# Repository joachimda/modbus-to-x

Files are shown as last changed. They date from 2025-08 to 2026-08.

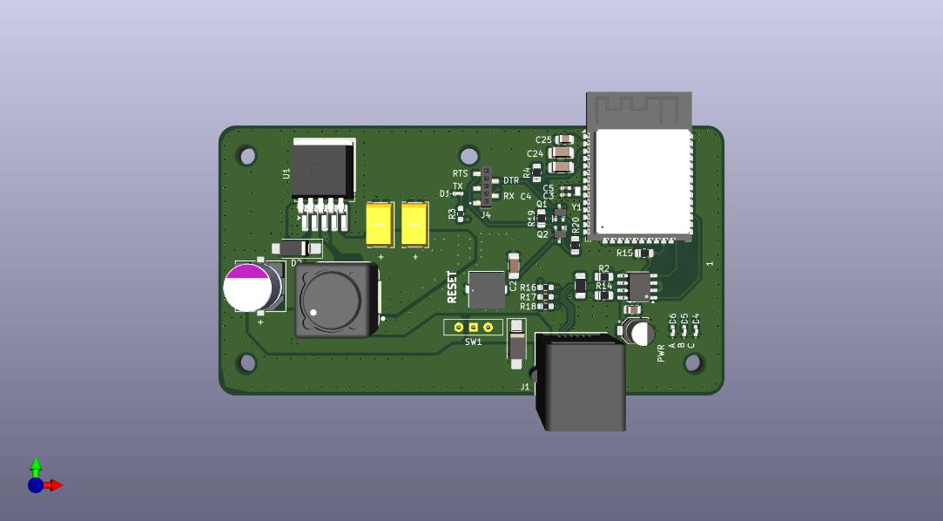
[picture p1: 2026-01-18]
hardware/mbx_3d_view.jpg

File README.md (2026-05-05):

# Modbus-to-X

An ESP32-based hardware and firmware stack that bridges RS-485/Modbus field devices to modern network services such as MQTT, with a configuration-first UX for installers and maintainers.

## Table of Contents
- [Overview](#overview)
- [Architecture](#architecture)
  - [Hardware](#hardware)
  - [Firmware](#firmware)
- [Getting Started](#getting-started)
  - [Prerequisites](#prerequisites)
  - [Build and Flash](#build-and-flash)
  - [Release Automation](#release-automation)
  - [Local UI Development](#local-ui-development)
- [Usage](#usage)
  - [First Boot and Network Setup](#first-boot-and-network-setup)
  - [Configuring Modbus Devices](#configuring-modbus-devices)
  - [MQTT Publishing](#mqtt-publishing)
- [Project Structure](#project-structure)
  - [Hardware Documentation](#hardware-documentation)
  - [Software Documentation](#software-documentation)
- [Acknowledgements](#acknowledgements)

## Overview
Modbus-to-X combines a custom ESP32 carrier board with firmware that polls Modbus RTU devices over RS-485, persists telemetry locally, and republishes structured payloads to MQTT brokers. 
The firmware exposes an onboard web interface for Wi-Fi provisioning, Modbus configuration, live device statistics, and log retrieval so field technicians can deploy the gateway without recompiling binaries.

## Architecture
The project is split between dedicated hardware design files and a PlatformIO firmware project. Hardware-specific documentation lives in [`hardware/`](hardware/); firmware, tooling, and UI assets live in [`software/`](software/).

### Hardware
- Four-layer ESP32 carrier featuring an ESP32-WROOM-32D module, MAX3485 RS-485 transceiver
- RJ12 Connector exposing differential RS-485 pair alongside field power for quick deployment.
- Wide input voltage range (4.5 - 40V)
- Supporting assets include datasheets, fabrication rules, and release notes for each board revision under `hardware/`.

### Firmware
- PlatformIO-based ESP32 application primarily built with the Arduino framework.
- Library dependencies: ModbusMaster, PubSubClient, ArduinoJson, and ESPAsyncWebServer for protocol handling and a dynamic UI backend.
- A custom partition table separates user configurations from UI components, leaving user configurations untouched on filesystem uploads.
- Boot sequence mounts filesystem partitions, starts the async web server ("MBX Server"), initializes the Modbus scheduler, and spins up the MQTT manager.
- Configuration data for the Modbus bus, devices, and MQTT settings is stored in `/conf/*.json` on the dedicated config SPIFFS partition (`cfg`) and hot-reloaded without reflashing.
- MQTT passwords are stored in NVS preferences; `/conf/mqtt.json` contains non-sensitive fields.
- Default wiring, RS-485 guard times, Wi-Fi AP Portal credentials, and OTA parameters are centralized in [`Config.h`](software/modbus-to-mqtt/include/Config.h).

## Getting Started

### Prerequisites
- Modbus-to-X hardware (v0.2 alpha or later) and Modbus RTU devices wired to the RS-485 terminals.
- 4.5–40 VDC field power (buck input validated in the current design) and a USB-to-UART adapter if not using OTA uploads.
- Development host with Python 3, [PlatformIO Core](https://platformio.org/install/cli), and a working `git` toolchain. Required Python build dependencies are installed automatically by `scripts/install_build_deps.py` when PlatformIO runs.

### Build and Flash
1. Clone the repository and enter the firmware workspace:
   ```bash
   git clone https://github.com/joachimda/modbus-to-x.git
   cd modbus-to-x/software/modbus-to-mqtt
   ```
2. Choose an environment in `platformio.ini`:
   - `mbx-custom-board-dev` — development build, serial upload (default).
   - `mbx-custom-board-dev-ota` — development build, OTA upload (configure `upload_port` for your device).
   - `mbx-custom-board-release` — release build (used by the GitHub Actions workflow).
   - `mbx-custom-board-release-primer` — primes a dev device to receive HTTP OTA updates.
3. Build the firmware (PlatformIO will fetch dependencies and embed git metadata):
   ```bash
   pio run
   ```
4. Flash via USB/UART or OTA by selecting the matching environment:
   ```bash
   # Serial upload
   pio run -e mbx-custom-board-dev -t upload

   # OTA upload to a provisioned gateway
   pio run -e mbx-custom-board-dev-ota -t upload
   ```
5. Upload the web UI and config assets to SPIFFS when they change:
   ```bash
   pio run -e mbx-custom-board-dev -t uploadfs
   ```

### Release Automation
Pushing a `v*` tag triggers the GitHub Actions workflow in `.github/workflows/main.yml` to build firmware + filesystem images and create a GitHub Release with the assets:
- `modbus-to-x.bin` (firmware)
- `modbus-to-x.fs.bin` (filesystem)
- `modbus-to-x.notes.txt` (release notes generated from the commit log since the previous tag)
- `modbus-to-x.manifest.json` (includes SHA-256 hashes and a signature generated from `OTA_SIGNING_KEY_PEM` and `KID`).

### Local UI Development
The `scripts/run_test_webserver.py` helper serves the `data/` directory with mocked API responses so you can iterate on the HTML/JS bundle without flashing the device:
```bash
cd software/modbus-to-mqtt
python scripts/run_test_webserver.py
# Visit http://127.0.0.1:8000
```
It injects correct MIME types, disables caching, and emulates `/api/stats/system`, `/api/events`, `/api/logs`, and `/api/system/reboot` for the SPA.

## Usage

### First Boot and Network Setup
1. Power the gateway; it will advertise a Wi-Fi AP using the defaults defined in `Config.h` (`MODBUS-MQTT-BRIDGE` / `you-shall-not-pass`).
2. Connect to the AP. The ESP will try getting 192.168.4.1 from DHCP. If supported on your OS, you will be prompted to open the Captive Portal and redirected automatically. If these fail, check your router for the device's IP address, and use your browser to open the configuration page `http://192.168.4.1/`. 
3. Follow the on-screen guidance to scan, join, or provision hidden networks, optionally specifying static IP parameters before saving.
4. After a successful network connection is established, reboot the device.

### Configuring Modbus Devices
- Use **Configure Modbus** to edit the RS-485 bus, add devices, and define datapoints. Modbus configurations are stored in the config partition at `/conf/config.json` and can be applied live without rebooting.
- Configuration files follow the schema in `data/conf/schema.json` (UI) and the example in `docs/configuration_examples/modbus.json`. Each datapoint specifies the function code, register address, data type, scale, and engineering units that will be published when polled.
- Per-device MQTT publishing and Home Assistant discovery can be toggled in the Modbus config; discovery publishes retained entity definitions for read/write datapoints.
  Example (excerpt):
  ```json
  {
    "devices": [
      {
        "name": "Boiler",
        "slaveId": 10,
        "mqttEnabled": true,
        "homeassistantDiscoveryEnabled": true,
        "dataPoints": [
          {
            "id": "temp",
            "name": "Temperature",
            "function": 4,
            "address": 100,
            "numOfRegisters": 1,
            "dataType": "int16",
            "scale": 0.1,
            "unit": "C",
            "topic": "plant/boiler/temp_c"
          }
        ]
      }
    ]
  }
  ```

### MQTT Publishing
- Configure broker host, port, credentials, and optional root topic via the **Configure MQTT** page or by editing `/conf/mqtt.json`. The firmware automatically extracts hostnames from URLs and persists the MQTT password in NVS preferences.
- When Modbus reads succeed, datapoint values are published to MQTT using either the per-datapoint topic override or the default pattern `<root>/<device>/<datapointId>` with slugified datapoint names as datapoint IDs.
- MQTT connectivity, Modbus statistics, and recent logs are visible on the dashboard.

## Project Structure
```
.
├── hardware/                 # Schematics, PCB layout, BOM assets, release notes
├── software/
│   └── modbus-to-mqtt/       # PlatformIO workspace with firmware, web UI, and tooling
└── README.md                 # This high-level overview
```

### Hardware Documentation
Detailed hardware notes, KiCad sources, datasheets, and per-revision release notes are kept in [`hardware/`](hardware/). Start with the latest folder under [`hardware/releases/`](hardware/releases/) (for example, `v0.2-alpha`) for the current board spin and consult the KiCad project in [`hardware/kicad_files/`](hardware/kicad_files/) for schematics, layout, and fabrication outputs.

### Software Documentation
The firmware entry point, reusable libraries, and static assets live under [`software/modbus-to-mqtt/`](software/modbus-to-mqtt/). Key references:
- [`src/`](software/modbus-to-mqtt/src/) – firmware modules for Modbus polling, MQTT connectivity, OTA, and the async web server.
- [`data/`](software/modbus-to-mqtt/data/) – web UI bundle and config schema served by the device (config data lives in the `/conf` partition at runtime).
- [`docs/configuration_examples/`](software/modbus-to-mqtt/docs/configuration_examples/) – JSON schemas and examples for Modbus and MQTT configuration.
- [`boards/`](software/modbus-to-mqtt/boards/) – custom PlatformIO board definition for the production hardware (ESP32, 16 MB flash).

## Acknowledgements
- Built on Espressif's ESP32 platform and the open-source libraries listed in `platformio.ini` (ModbusMaster, PubSubClient, ArduinoJson, ESPAsyncWebServer).
- Component footprints and 3D models sourced from vendor or third-party libraries included under `hardware/kicad_files/lib/` with accompanying license terms in `hardware/kicad_files/lib/licenses`.

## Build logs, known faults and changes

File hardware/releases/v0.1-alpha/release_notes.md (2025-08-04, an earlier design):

# Modbus to X v0.1-alpha
##### First Alpha hardware release.
Includes test points, RS485 transceiver, EEPROMS ESP32 WROOM module.

##### KiCad notes
* Fabrication specs targets JLCPCB capabilities.
* Minor silkscreen DRC warnings ignored per fabrication specs.

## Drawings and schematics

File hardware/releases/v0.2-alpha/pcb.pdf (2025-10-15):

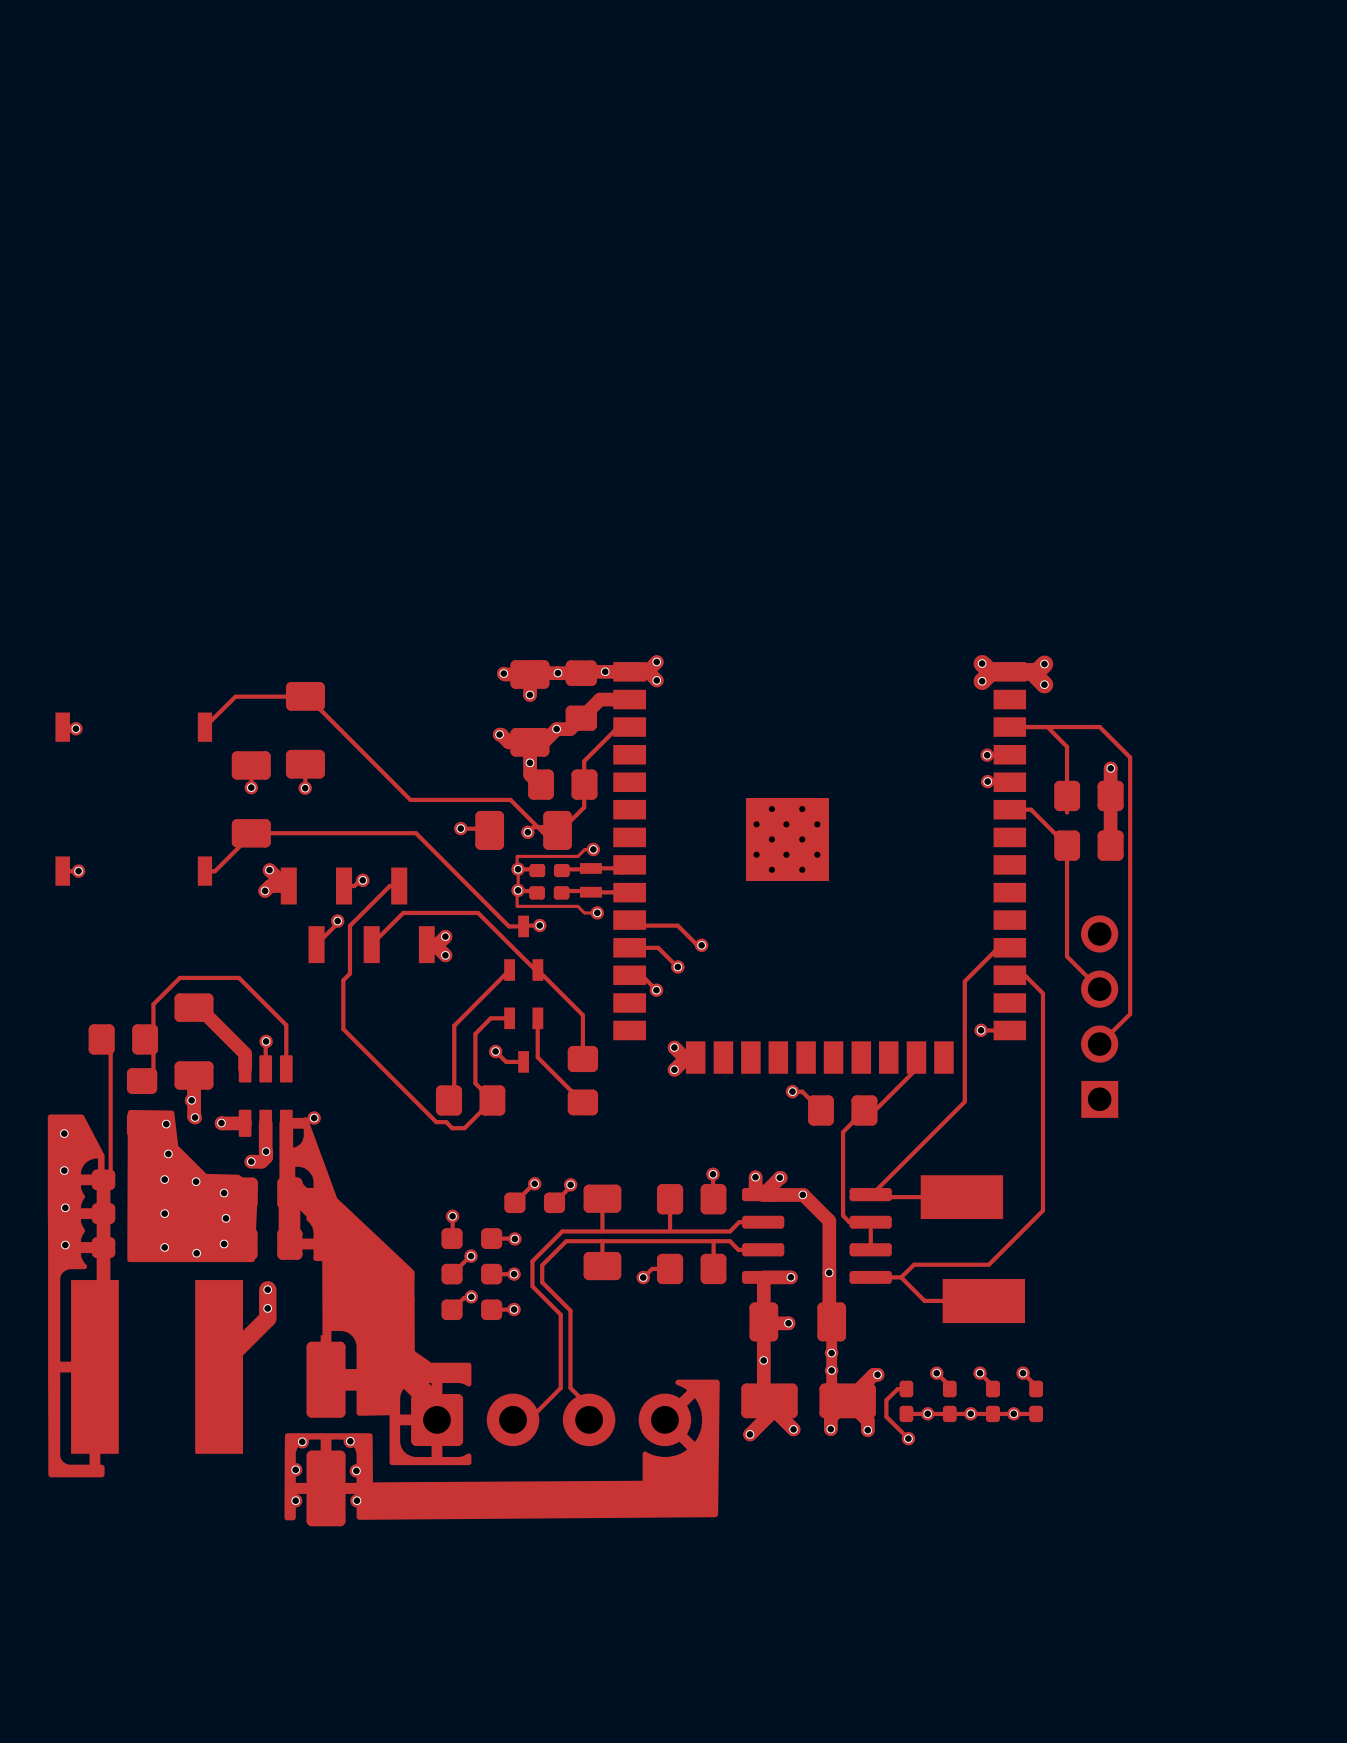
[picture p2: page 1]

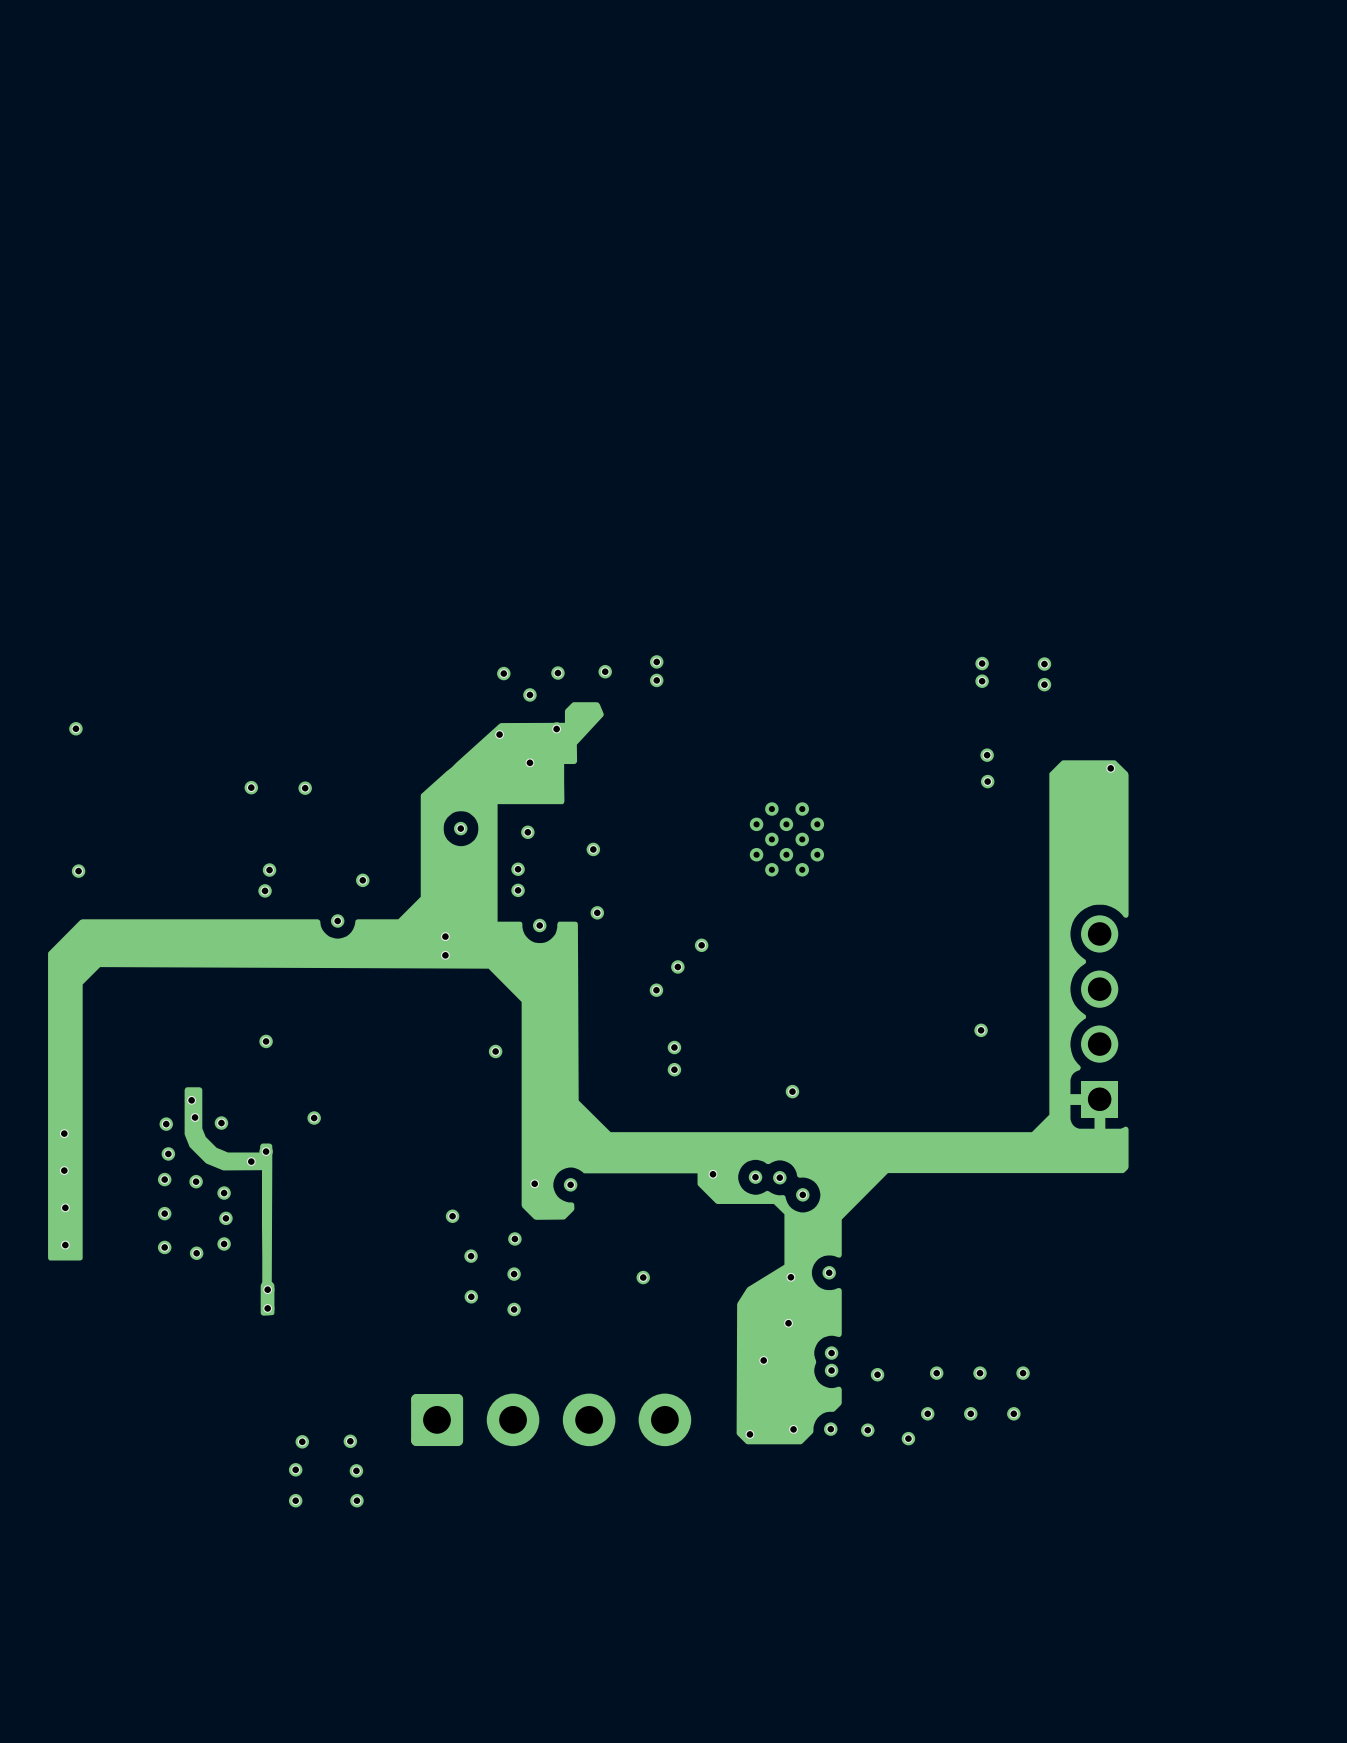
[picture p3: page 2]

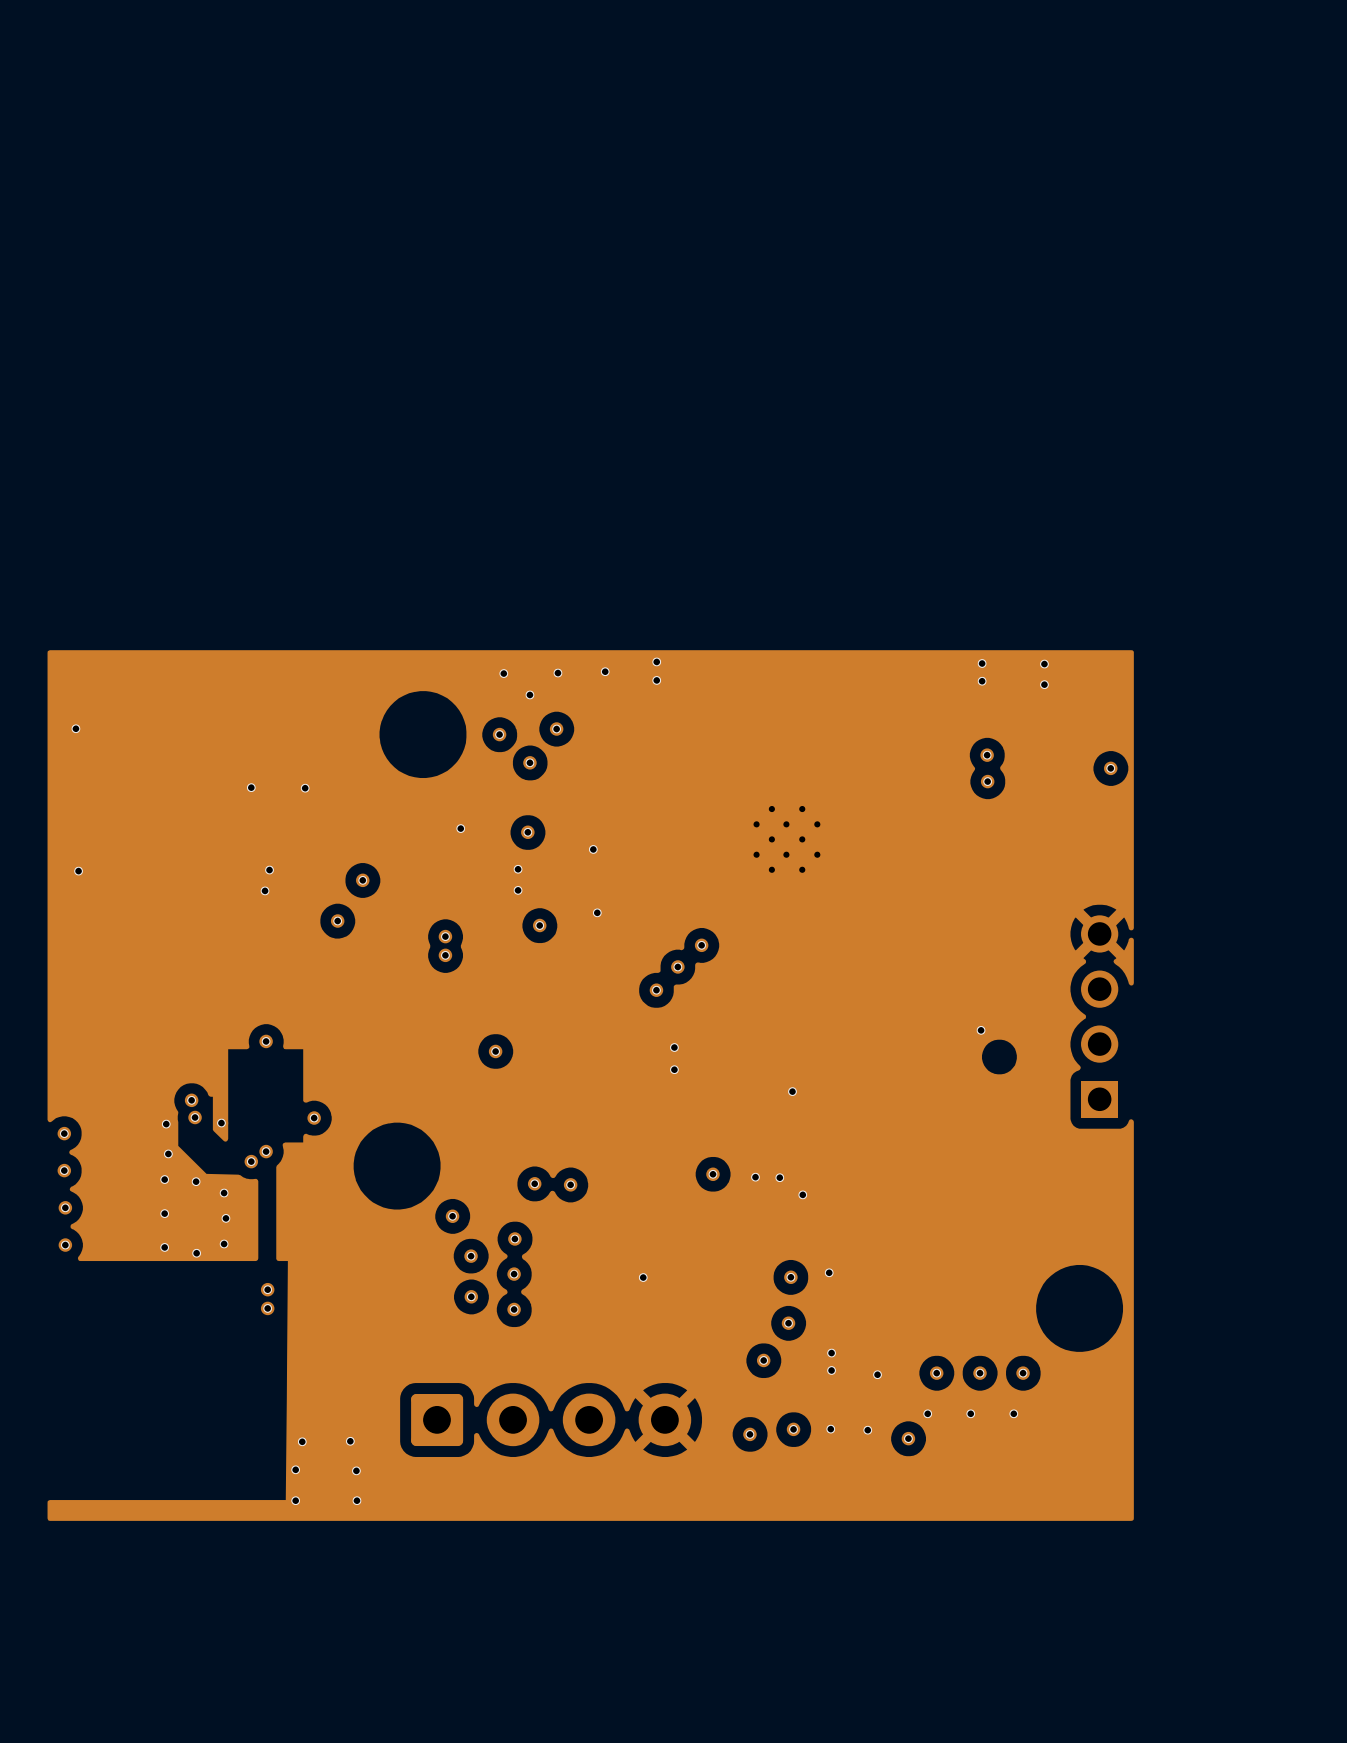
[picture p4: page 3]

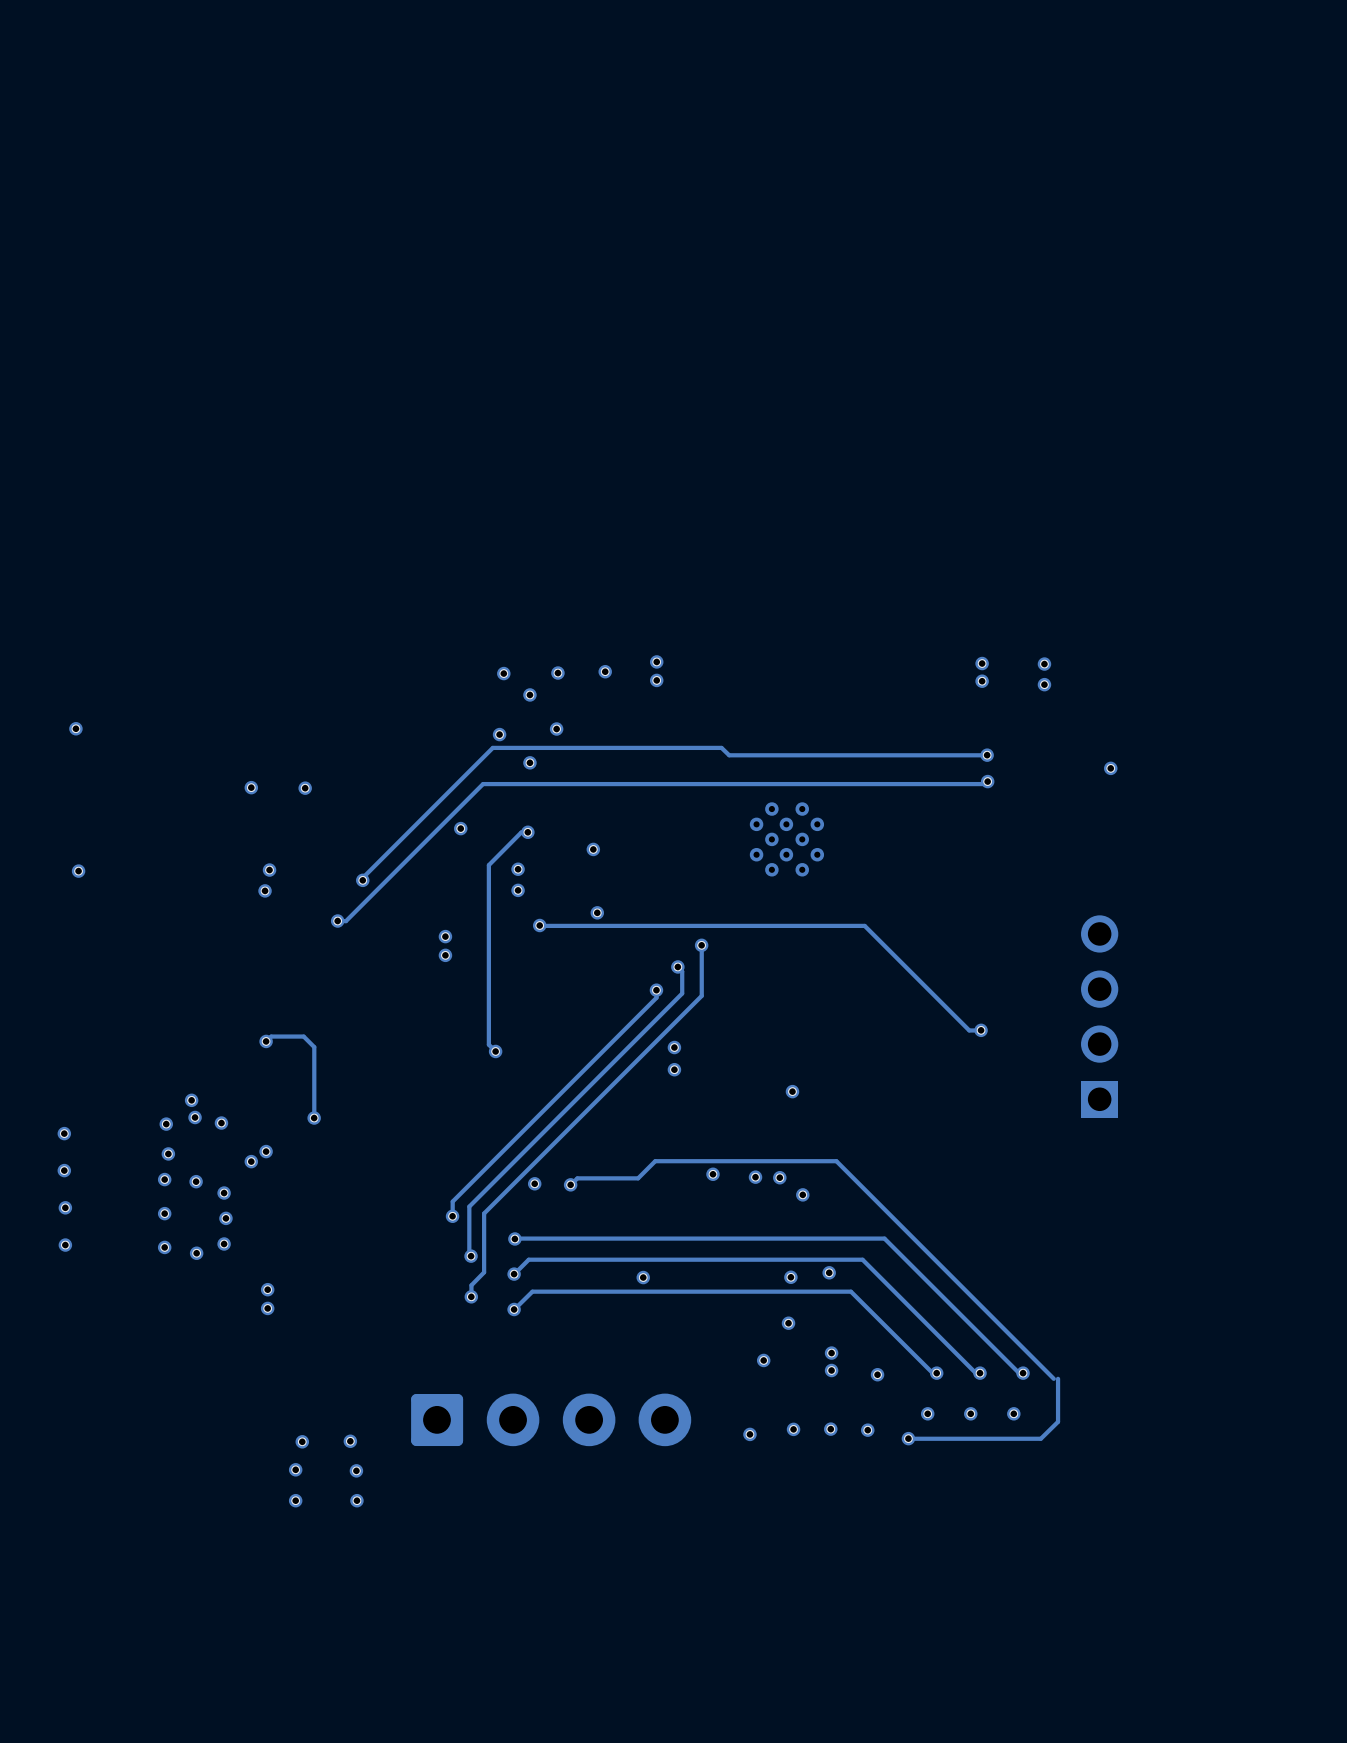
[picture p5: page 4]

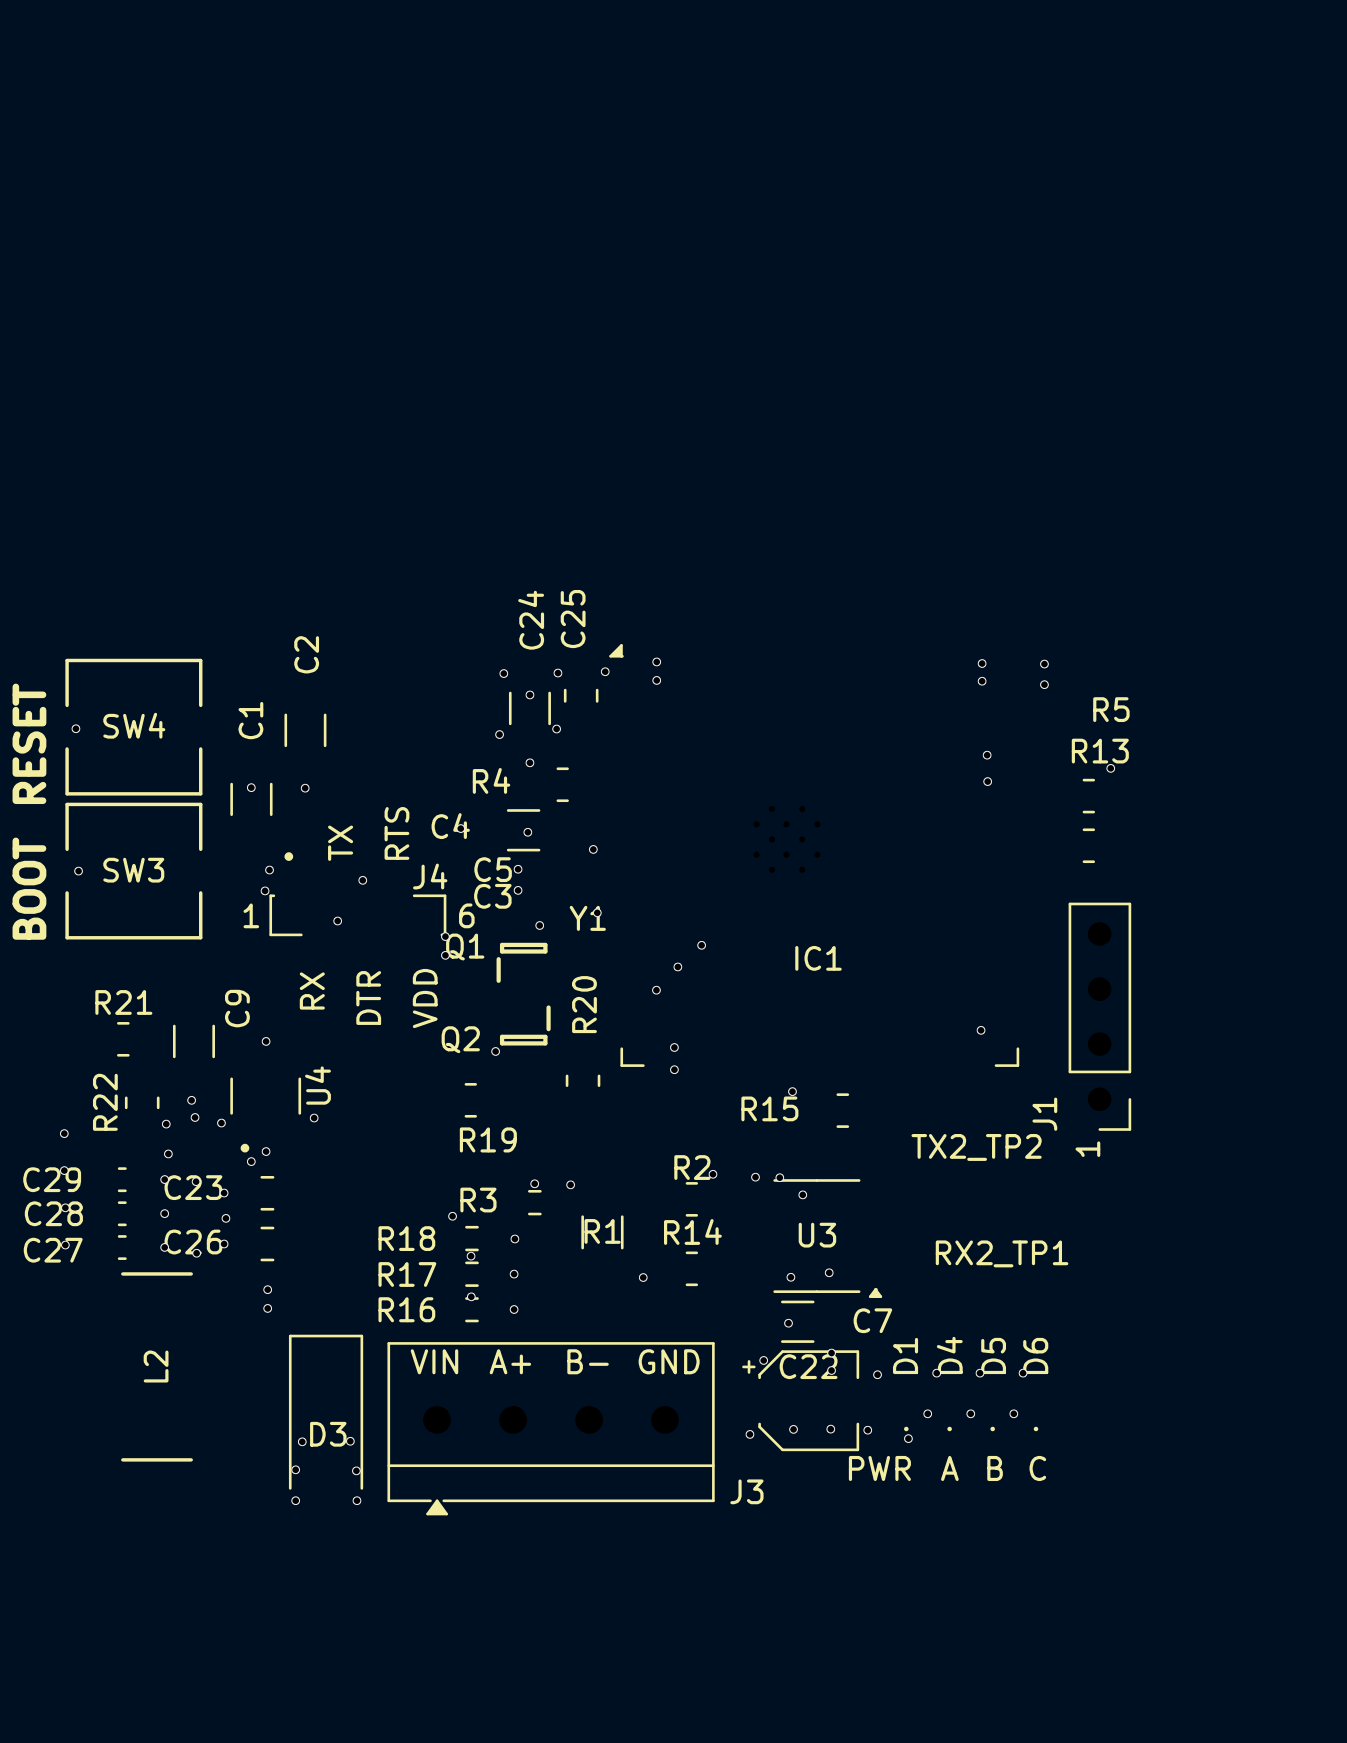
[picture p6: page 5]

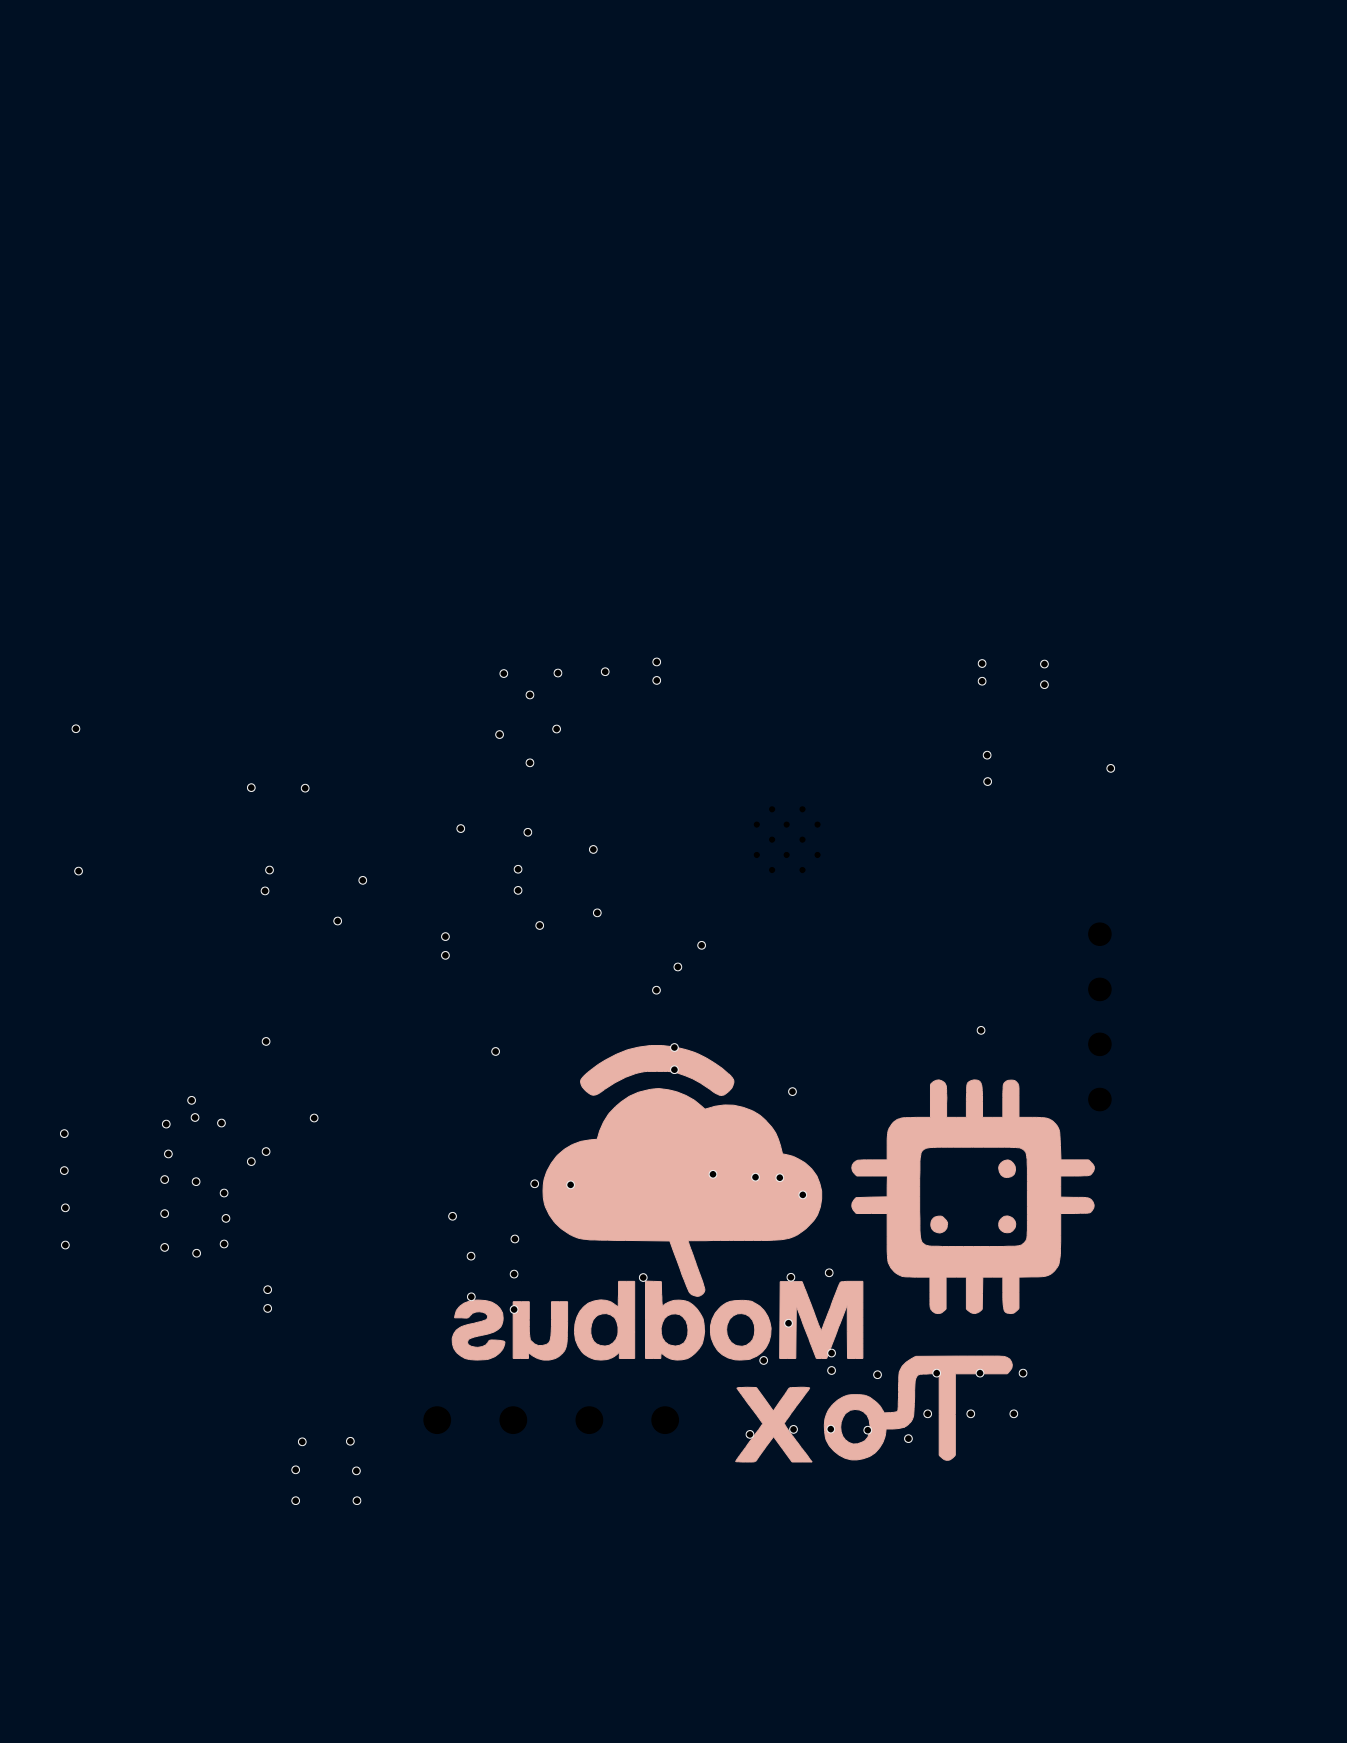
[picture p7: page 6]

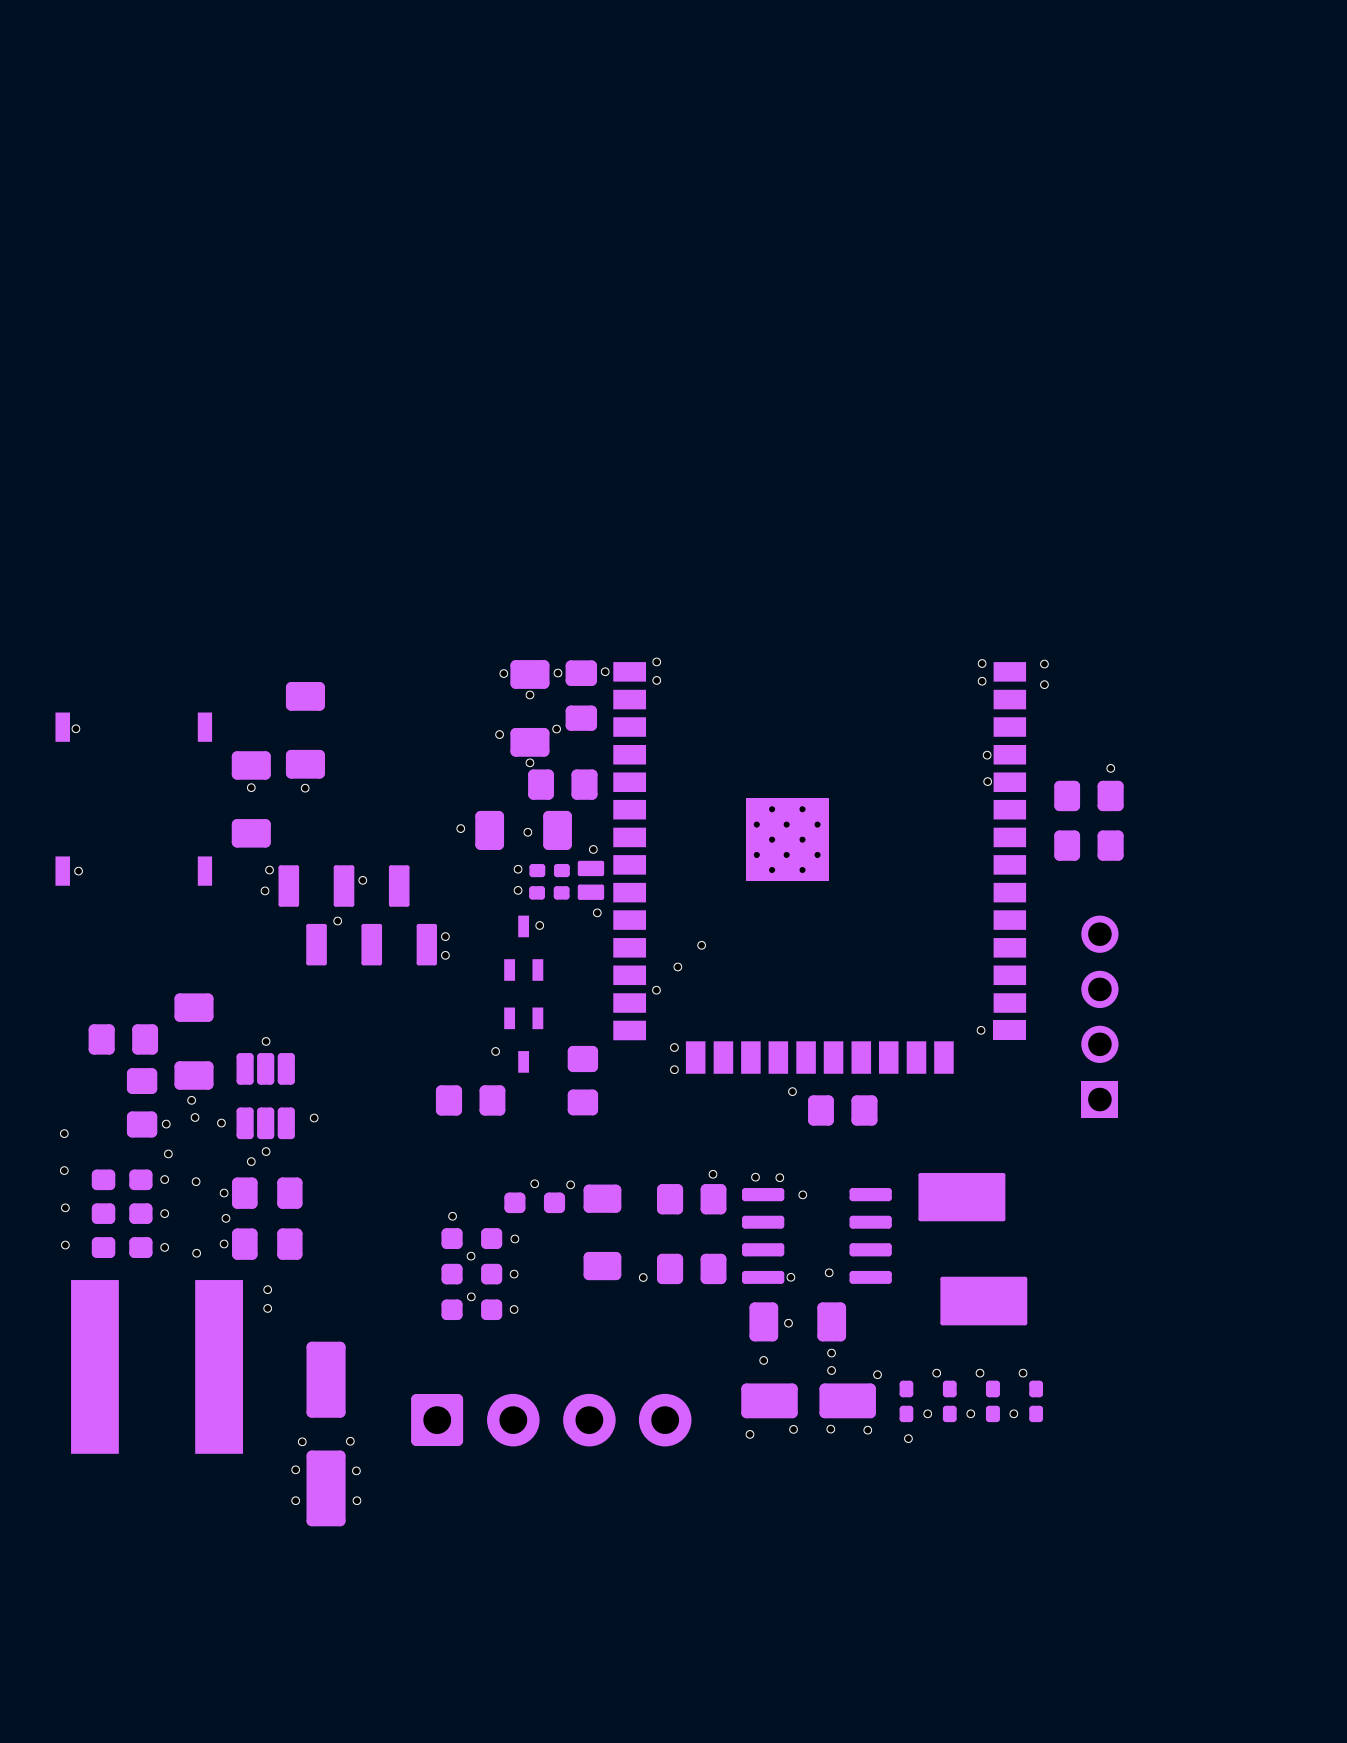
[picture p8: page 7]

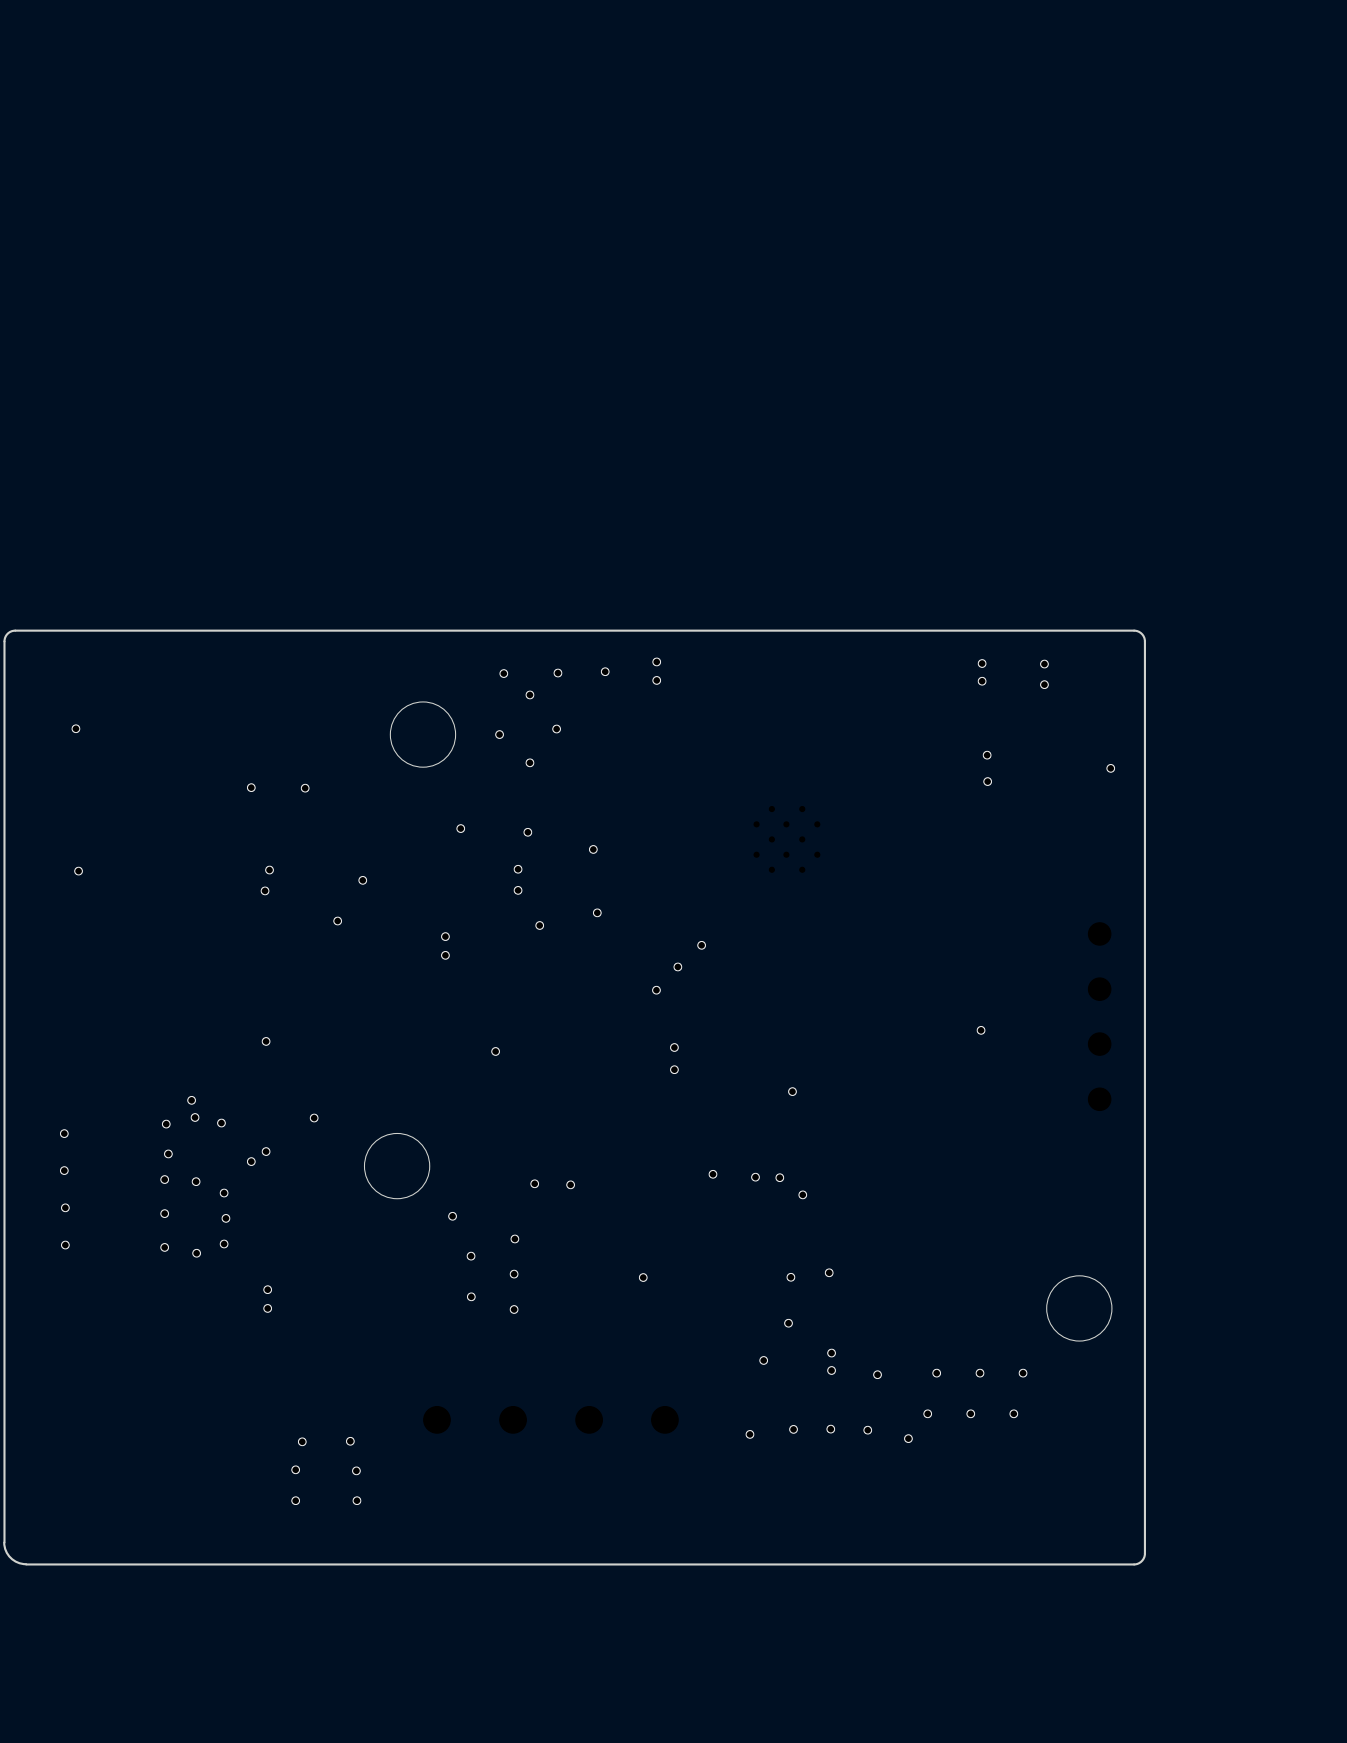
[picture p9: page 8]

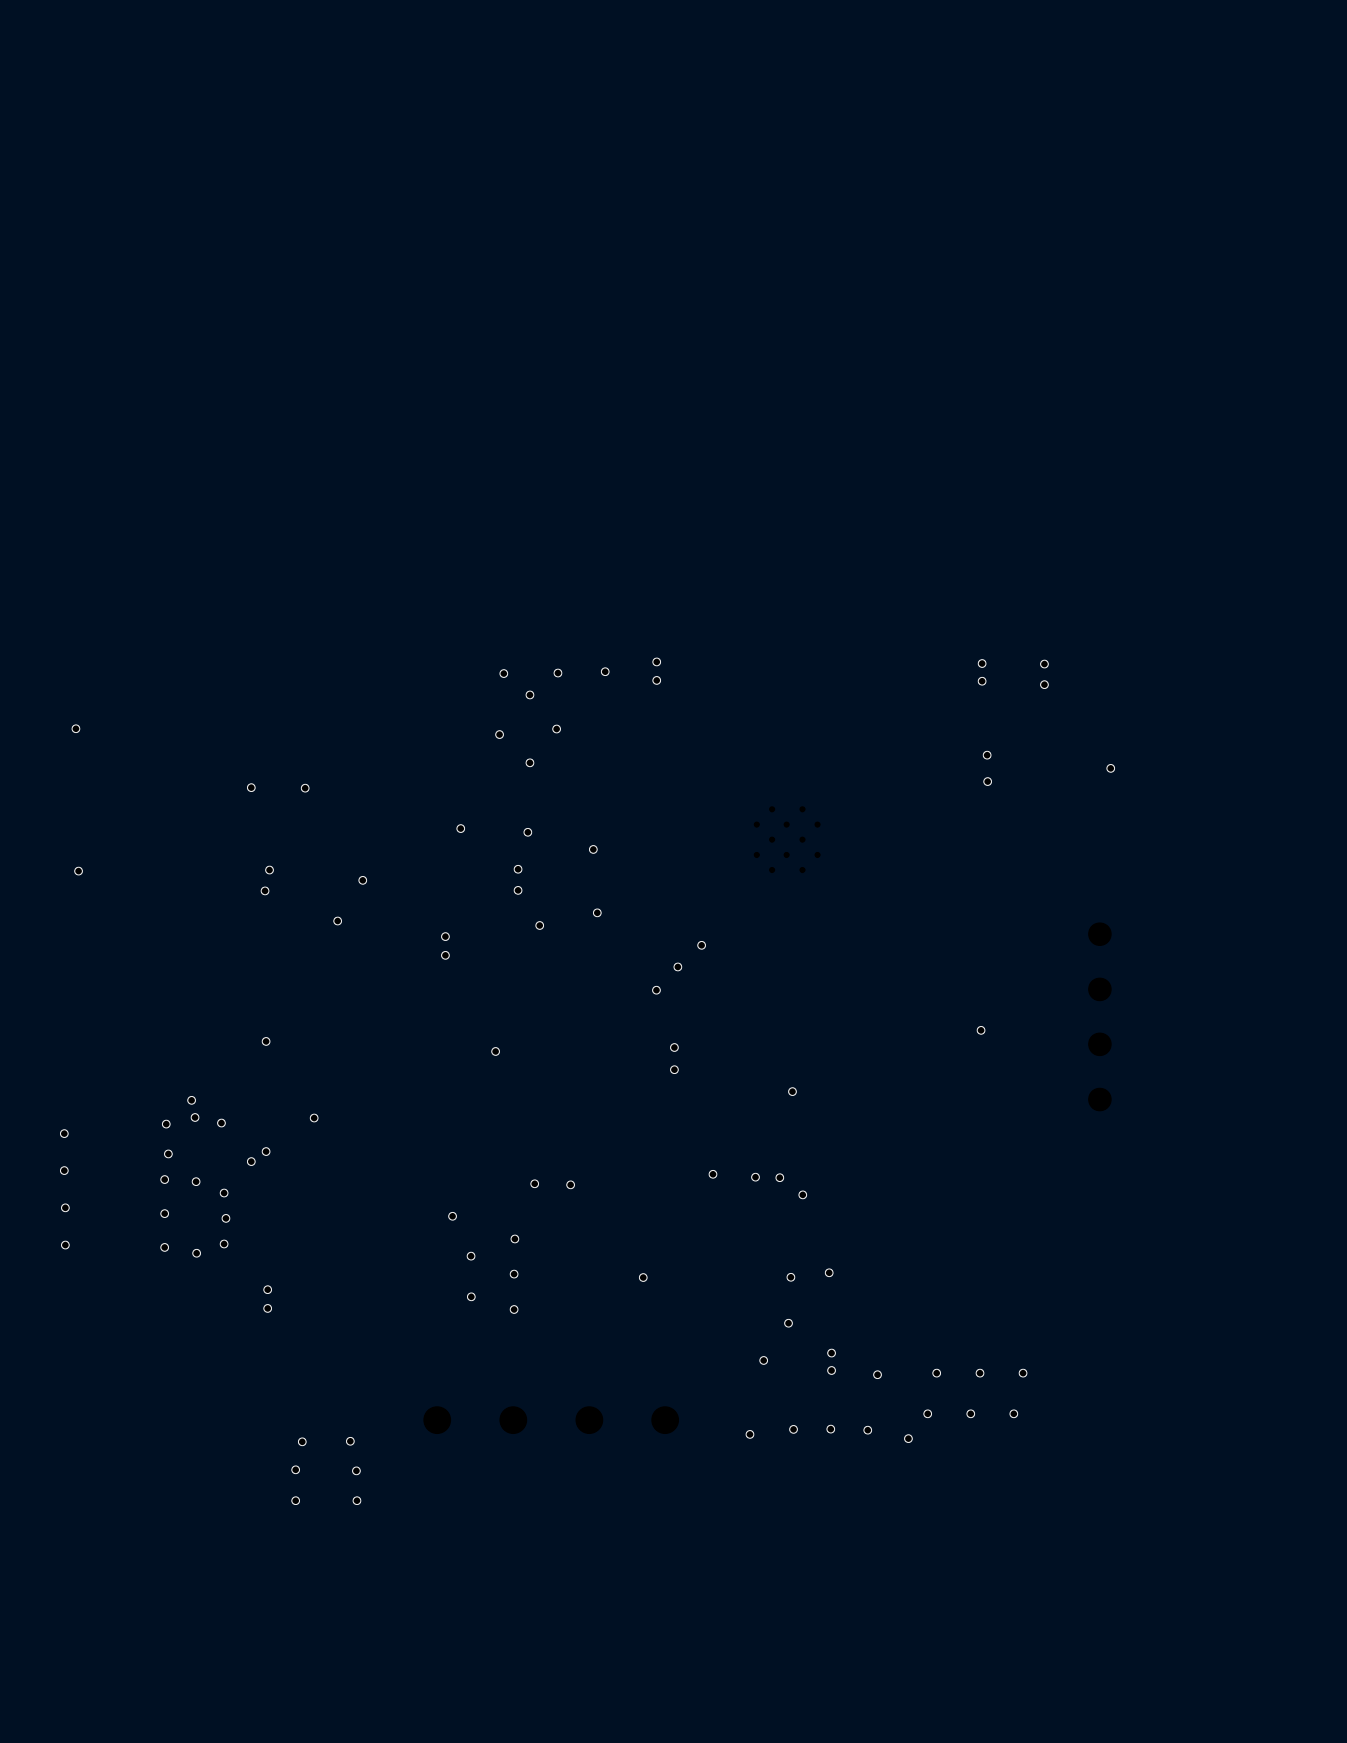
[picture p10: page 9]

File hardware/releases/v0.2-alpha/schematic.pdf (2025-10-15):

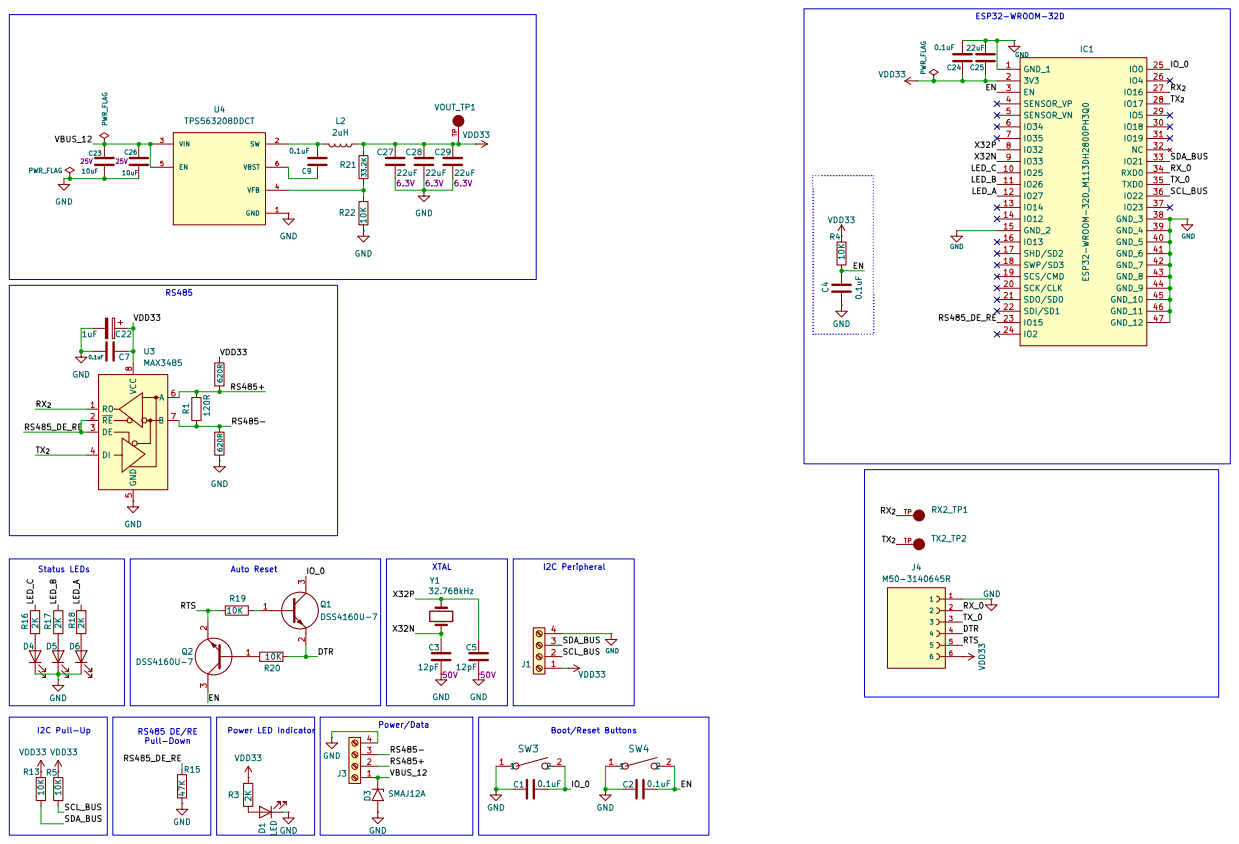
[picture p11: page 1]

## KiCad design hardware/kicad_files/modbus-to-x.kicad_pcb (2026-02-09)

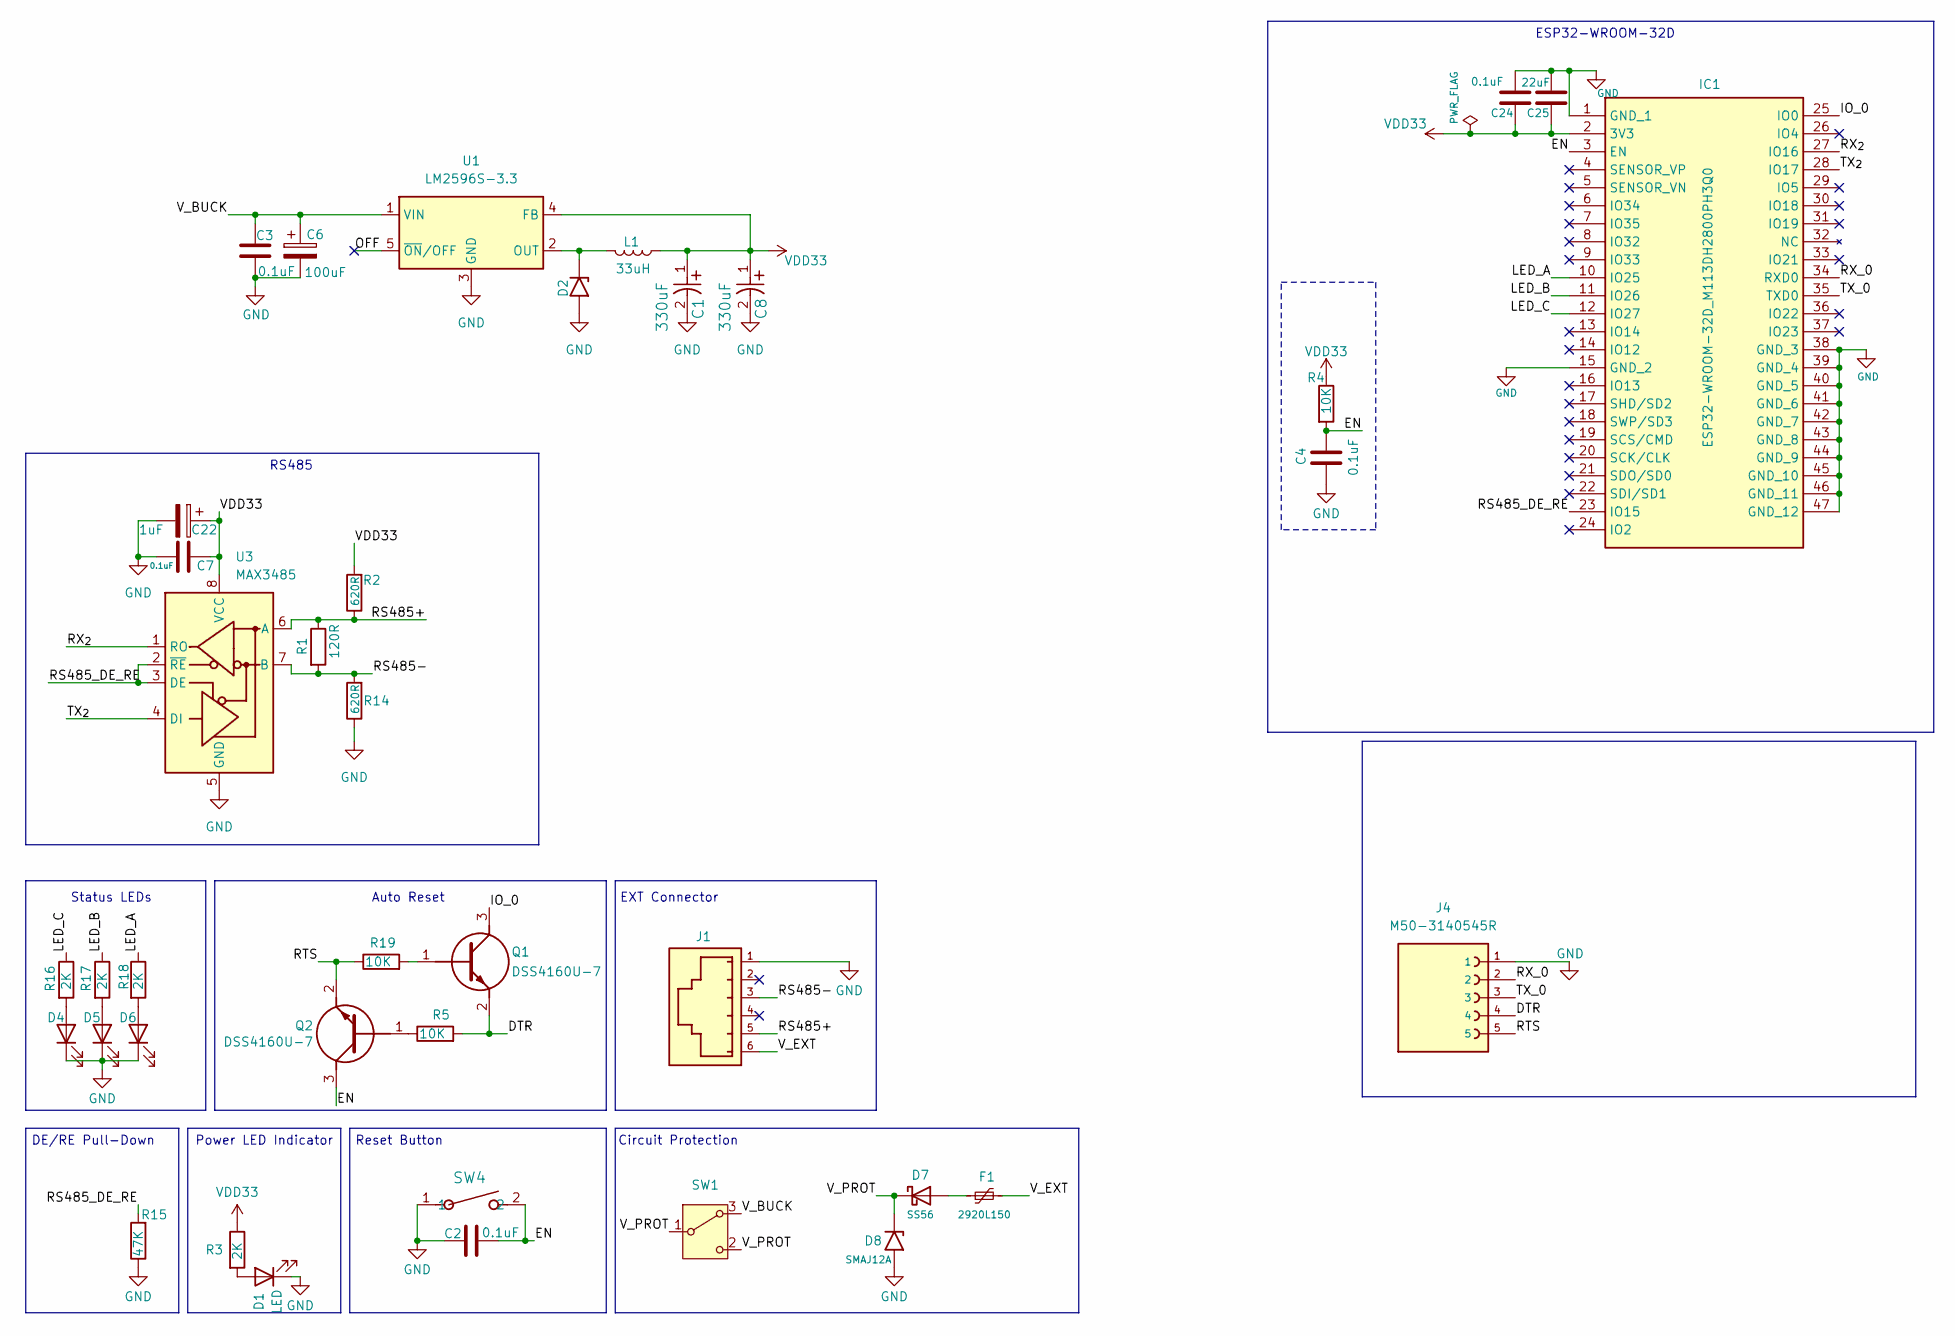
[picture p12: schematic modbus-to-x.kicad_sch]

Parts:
C1, C8: 330uF; T495D337K006ATE100; PartNo T495D337K006ATE100
C2, C4, C7, C24: 0.1uF; C_0805_2012Metric; Voltage 50V; PartNo GCD21BR71H104KA01L
C3: 0.1uF; C_0603_1608Metric; Voltage 50V; PartNo C0603C104K5RACTU
C6: 100uF; 25SVPF100M; Voltage 25V; PartNo 25SVPF100M
C22: 1uF; CP_Elec_4x5.4; Voltage 50V; PartNo NACE1R0M50V4X5.5TR15F
C25: 22uF; C_0805_2012Metric_Pad1.18x1.45mm_HandSolder; Voltage 16V; PartNo CL21A226MOCLRNC
D1, D4, D5, D6: LED; LED_0402_1005Metric_Pad0.77x0.64mm_HandSolder; PartNo LW QH8G-Q2OO-3K5L-1
D2: B340LA-13-F; D_SMA_Handsoldering; PartNo B340LA-13-F
D7: SS56; D_SMA; PartNo SS56
D8: SMAJ12A; D_SMA; PartNo SMAJ12A
F1: 2920L150; Fuse_2920_7451Metric; PartNo 2920L150/60MR
IC1: ESP32-WROOM-32D_M113DH2800PH3Q0; ESP32-WROOM-32D_ANT_SILK_REMOVED; PartNo M113DH2800PH3Q0
J1: 615006138421; RJ12_615006138421
J4: M50-3140545R; HARWIN_M50-3140545R; PartNo M50-3140545R
L1: 33uH; 7447709330; PartNo 7447709330
Q1, Q2: DSS4160U-7; SOT65P210X110-3N; PartNo DSS4160U-7
R1: 120R; R_1206_3216Metric_Pad1.30x1.75mm_HandSolder; PartNo RC1206FR-13120RL
R2, R14: 620R; R_0805_2012Metric_Pad1.20x1.40mm_HandSolder; PartNo RND 1550805S8F6200T5E
R3, R16, R17, R18: 2K; R_0603_1608Metric_Pad0.98x0.95mm_HandSolder; PartNo RND 155TC0325B2001T5H
R4, R5, R19: 10K; R_0603_1608Metric; PartNo RT0603DRE0710KL
R15: 47K; R_0805_2012Metric_Pad1.20x1.40mm_HandSolder; PartNo RND 1550805S8F4702T5E
SW1: SW_Wuerth_450301014042; SW_Slide-03_Wuerth-WS-SLTV_10x2.5x6.4_P2.54mm
SW4: 3983; SW_3983_ADA; PartNo Adafruit-3983
U1: LM2596S-3.3; TO-263-5_TabPin3
U3: MAX3485; SOIC-8_3.9x4.9mm_P1.27mm; PartNo MAX3485CSA+T

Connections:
/DTR: J4.4, Q1.2 (E), R5.2
/EN: C2.1, C4.1, IC1.3 (EN), Q2.3 (C), R4.2, SW4.2
/IO_0: IC1.25 (IO0), Q1.3 (C)
/LED_A: IC1.10 (IO25), R18.1
/LED_B: IC1.11 (IO26), R17.1
/LED_C: IC1.12 (IO27), R16.1
/OFF: U1.5 (~ON/OFF)
/RS485+: J1.5, R1.1, R2.1, U3.6 (A)
/RS485-: J1.3, R1.2, R14.2, U3.7 (B)
/RS485_DE_RE: IC1.23 (IO15), R15.2, U3.2 (~RE), U3.3 (DE)
/RTS: J4.5, Q2.2 (E), R19.1
/RX_0: IC1.34 (RXD0), J4.2
/RX_{2}: IC1.27 (IO16), U3.1 (RO)
/TX_0: IC1.35 (TXD0), J4.3
/TX_{2}: IC1.28 (IO17), U3.4 (DI)
/V_BUCK: C3.1, C6.1, SW1.3 (A), U1.1 (VIN)
/V_EXT: F1.2, J1.6
/V_PROT: D7.1 (K), D8.1 (A1), SW1.1 (B), SW1.2 (C)
GND: C1.2, C2.2, C3.2, C4.2, C6.2, C7.2, C8.2, C22.2, C24.1, C25.1, D1.1 (K), D2.2 (A2), D4.1 (K), D5.1 (K), D6.1 (K), D8.2 (A2), IC1.1 (GND_1), IC1.15 (GND_2), IC1.38 (GND_3), IC1.39 (GND_4), IC1.40 (GND_5), IC1.41 (GND_6), IC1.42 (GND_7), IC1.43 (GND_8), IC1.44 (GND_9), IC1.45 (GND_10), IC1.46 (GND_11), IC1.47 (GND_12), J1.1, J4.1, R14.1, R15.1, SW4.1, U1.3 (GND), U3.5 (GND)
unnamed: D1.2 (A), R3.2
unnamed: D2.1 (A1), L1.2, U1.2 (OUT)
unnamed: D4.2 (A), R16.2
unnamed: D5.2 (A), R17.2
unnamed: D6.2 (A), R18.2
unnamed: D7.2 (A), F1.1
unnamed: Q1.1 (B), R19.2
unnamed: Q2.1 (B), R5.1
VDD33: C1.1, C7.1, C8.1, C22.1, C24.2, C25.2, IC1.2 (3V3), L1.1, R2.2, R3.1, R4.1, U1.4 (FB), U3.8 (VCC)

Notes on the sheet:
EXT Connector
Power LED Indicator
Auto Reset
ESP32-WROOM-32D
Circuit Protection
Status LEDs
Reset Button
RS485
DE/RE Pull-Down

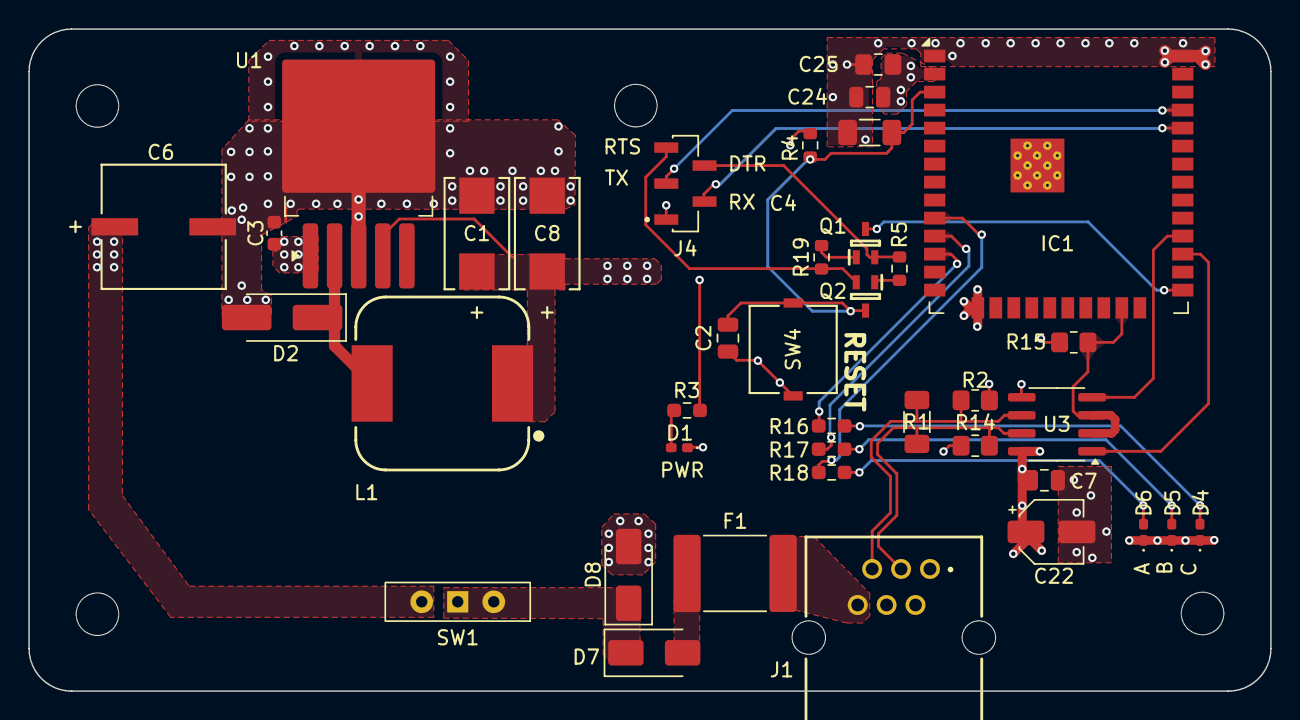
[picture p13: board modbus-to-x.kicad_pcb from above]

Board: 4 copper layers, 87.6 x 46.7 mm, 39 parts (0 on the bottom side), 27 nets.

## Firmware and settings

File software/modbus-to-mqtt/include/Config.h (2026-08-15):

#ifndef CONFIG_H
#define CONFIG_H

/****************************************************
 * WIRING
 ****************************************************/
#ifndef RS485_DERE_PIN
#define RS485_DERE_PIN 15
#endif

// Guard delay around RS485 direction changes (in microseconds)
// Helps transceiver settle and ensures RX is enabled before responses arrive.
#ifndef RS485_DIR_GUARD_US
#define RS485_DIR_GUARD_US 1000
#endif

// Drop one or more leading 0x00 bytes seen immediately at the start of RX.
// Some RS485 transceivers or wiring transitions can produce a spurious 0x00
// which misaligns the Modbus frame. Enable to filter these.
#ifndef RS485_DROP_LEADING_ZERO
#define RS485_DROP_LEADING_ZERO 0
#endif

// When dropping leading zeros, wait up to this many microseconds for the
// first non-zero byte to arrive so we can substitute it as the first byte.
// In most cases, 500-2000 us is enough.
#ifndef RS485_FIRSTBYTE_WAIT_US
#define RS485_FIRSTBYTE_WAIT_US 2500
#endif

#ifndef WIFI_LED_A_PIN
#define WIFI_LED_A_PIN 25
#endif

#ifndef MQTT_LED_B_PIN
#define MQTT_LED_B_PIN 26
#endif
#ifndef MB_LED_C_PIN
#define MB_LED_C_PIN 27
#endif

/****************************************************
 * MODBUS
 ****************************************************/
#ifndef DEFAULT_MODBUS_BAUD_RATE
#define DEFAULT_MODBUS_BAUD_RATE 9600
#endif

#ifndef DEFAULT_MODBUS_MODE
#define DEFAULT_MODBUS_MODE "8N1"
#endif

#define MODBUS_SLAVE_ID 1

/****************************************************
 * PREFERENCE STORAGE
 ****************************************************/

#define MQTT_PREFS_NAMESPACE "mqtt"

/****************************************************
 * MQTT
 ****************************************************/
#define MQTT_RECONNECT_INTERVAL_MS 5000

#ifndef MQTT_BUFFER_SIZE
#define MQTT_BUFFER_SIZE 4096
#endif

#ifndef MQTT_COMMAND_QUEUE_DEPTH
#define MQTT_COMMAND_QUEUE_DEPTH 12
#endif

#ifndef MQTT_COMMAND_WAIT_MS
#define MQTT_COMMAND_WAIT_MS 3000
#endif

#ifndef MQTT_COMMANDS_PER_CYCLE
#define MQTT_COMMANDS_PER_CYCLE 6
#endif

#ifndef MODBUS_COMMAND_QUEUE_DEPTH
#define MODBUS_COMMAND_QUEUE_DEPTH 8
#endif

#ifndef MODBUS_COMMAND_WAIT_MS
#define MODBUS_COMMAND_WAIT_MS 5000
#endif

#ifndef MODBUS_COMMANDS_PER_CYCLE
#define MODBUS_COMMANDS_PER_CYCLE 8
#endif

#ifndef RUNTIME_HTTP_JOB_QUEUE_DEPTH
#define RUNTIME_HTTP_JOB_QUEUE_DEPTH 8
#endif

#ifndef RUNTIME_HTTP_WORKER_COUNT
#define RUNTIME_HTTP_WORKER_COUNT 3
#endif

// A job can be either queued or owned by one worker. Keeping one completion
// slot for every such job lets workers hand responses to the Arduino loop
// without waiting or touching AsyncTCP from their own task contexts.
#ifndef RUNTIME_HTTP_RESPONSE_QUEUE_DEPTH
#define RUNTIME_HTTP_RESPONSE_QUEUE_DEPTH (RUNTIME_HTTP_JOB_QUEUE_DEPTH + RUNTIME_HTTP_WORKER_COUNT)
#endif

/****************************************************
 * OTA
 ****************************************************/
#ifndef OTA_HTTP_ENABLED
#define OTA_HTTP_ENABLED 1
#endif
#ifndef OTA_HTTP_MANIFEST_URL
#define OTA_HTTP_MANIFEST_URL "https://github.com/joachimda/modbus-to-x/releases/latest/download/modbus-to-x.manifest.json"
#endif
#ifndef OTA_HTTP_RELEASES_API_URL
#define OTA_HTTP_RELEASES_API_URL "https://api.github.com/repos/joachimda/modbus-to-x/releases?per_page=1"
#endif
#ifndef OTA_HTTP_DEVICE
#define OTA_HTTP_DEVICE "modbus-to-x"
#endif
#ifndef OTA_HTTP_INTERVAL_MS
#define OTA_HTTP_INTERVAL_MS (6UL * 60UL * 60UL * 1000UL)
#endif
#ifndef OTA_HTTP_CA_CERT_PEM
#define OTA_HTTP_CA_CERT_PEM nullptr
#endif
#ifndef OTA_HTTP_FORCE_UPDATE_ON_NEW_VERSION
#define OTA_HTTP_FORCE_UPDATE_ON_NEW_VERSION 1
#endif

#ifndef DEV_OTA_ARDUINO_PASS
#define DEV_OTA_ARDUINO_PASS ""
#endif
#ifndef DEV_OTA_ENABLED
#define DEV_OTA_ENABLED 0
#endif

/****************************************************
 * WIFI SETUP
 ****************************************************/
#ifndef DEFAULT_AP_SSID
#define DEFAULT_AP_SSID "MODBUS-MQTT-BRIDGE"
#endif

#ifndef DEFAULT_AP_PASS
#define DEFAULT_AP_PASS "you-shall-not-pass"
#endif

#ifndef DEFAULT_HOSTNAME
#define DEFAULT_HOSTNAME "modbus-to-x"
#endif

/****************************************************
 * System
 ****************************************************/
#ifndef SERIAL_OUTPUT_BAUD
#define SERIAL_OUTPUT_BAUD 115200
#endif
#endif

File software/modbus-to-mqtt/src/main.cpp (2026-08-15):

#include <Arduino.h>
#include <SPIFFS.h>
#include "storage/ConfigFs.h"
#include "SerialLogger.h"
#include "modbus/ModbusManager.h"
#include "network/mbx_server/MBXServer.h"
#include "Config.h"
#include <network/mbx_server/MBXServerHandlers.h>

#include "mqtt/MqttSubscriptionHandler.h"
#include "services/IndicatorService.h"
#include "services/ota/HttpOtaService.h"
#include <esp_system.h>

#include "logging/MemoryLogger.h"

#ifndef FW_VERSION
#define FW_VERSION "dev"
#endif

Logger logger;
MemoryLogger memory_logger(300);
MqttSubscriptionHandler mqtt_subscription_Handler(&logger);
WiFiClient wifiClient;
PubSubClient pubsub_client(wifiClient);
MqttManager mqtt_manager(&mqtt_subscription_Handler, &pubsub_client, &logger);
SerialLogger serial_logger(Serial);
ModbusManager modbus_manager(&logger);
AsyncWebServer server(80);
DNSServer dns;
MBXServer mbx_server(&server, &dns, &logger);

void setupEnvironment() {
    logger.useDebug(true);
    Serial.begin(SERIAL_OUTPUT_BAUD);
}

void setupFs(const Logger * l ) {
    if (!SPIFFS.begin(true, "/spiffs", 10, "spiffs")) {
        l->logError("setupFs() - An error occurred while mounting SPIFFS");
        return;
    }
    l->logDebug("setupFs() - SPIFFS mounted");
    if (!ConfigFS.begin(true, ConfigFs::kBasePath, 10, ConfigFs::kPartitionLabel)) {
        l->logError("setupFs() - An error occurred while mounting config FS");
        return;
    }
    l->logDebug("setupFs() - Config FS mounted");
}

void setup() {
    setupEnvironment();
    logger.addTarget(&serial_logger);
    logger.addTarget(&memory_logger);
    logger.logDebug("setup() - logger initialized");

    // Abnormal reset banner for UI visibility
    switch (esp_reset_reason()) {
        case ESP_RST_UNKNOWN:
        case ESP_RST_PANIC:
        case ESP_RST_INT_WDT:
        case ESP_RST_TASK_WDT:
        case ESP_RST_WDT:
        case ESP_RST_BROWNOUT: {
            const char *reasonStr =
                (esp_reset_reason() == ESP_RST_UNKNOWN) ? "Unknown" :
                (esp_reset_reason() == ESP_RST_PANIC) ? "Panic" :
                (esp_reset_reason() == ESP_RST_INT_WDT) ? "Interrupt WDT" :
                (esp_reset_reason() == ESP_RST_TASK_WDT) ? "Task WDT" :
                (esp_reset_reason() == ESP_RST_WDT) ? "Other WDT" :
                (esp_reset_reason() == ESP_RST_BROWNOUT) ? "Brownout" : "";
            const String msg = String("=== Abnormal reset detected: ") + reasonStr + " ===";
            memory_logger.logWarning(msg.c_str());
            break;
        }
        default: break;
    }
    setupFs(&logger);

    IndicatorService::instance().begin();

    mqtt_manager.begin();
    MBXServerHandlers::setMemoryLogger(&memory_logger);
    MBXServerHandlers::setMqttManager(&mqtt_manager);
    modbus_manager.setMqttManager(&mqtt_manager);
    MBXServerHandlers::setModbusManager(&modbus_manager);
    if (!MBXServerHandlers::beginRuntimeWorker()) {
        logger.logError("setup() - Failed to start bounded runtime HTTP worker");
    }

    // Establish the Arduino-loop Modbus owner and its mailbox before HTTP
    // callbacks can submit configuration or ad hoc bus requests.
    logger.logDebug("setup() - Starting modbus manager");
    modbus_manager.begin();

    logger.logDebug("setup() - Starting MBX Server");
    mbx_server.begin();

#if OTA_HTTP_ENABLED
    if (OTA_HTTP_MANIFEST_URL[0] != '\0') {
        HttpOtaService::begin(&logger, OTA_HTTP_MANIFEST_URL, OTA_HTTP_DEVICE, FW_VERSION, OTA_HTTP_CA_CERT_PEM);
        HttpOtaService::setIntervalMs(OTA_HTTP_INTERVAL_MS);
    } else {
        logger.logWarning("HTTP-OTA: OTA_HTTP_MANIFEST_URL not set");
    }
#endif

    logger.logDebug("setup() - complete");
}

void loop() {
    MBXServer::loop();
    modbus_manager.loop();
#if OTA_HTTP_ENABLED
    HttpOtaService::loop();
#endif
    delay(10);
}

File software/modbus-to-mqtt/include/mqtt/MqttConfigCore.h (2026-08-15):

#ifndef MODBUS_TO_MQTT_MQTTCONFIGCORE_H
#define MODBUS_TO_MQTT_MQTTCONFIGCORE_H

#include <array>
#include <cstddef>
#include <cstdint>
#include <string>
#include <utility>

namespace MqttConfigCore {

// Authoritative MQTT connection-field limits. Sizes exclude the trailing NUL
// retained by PreparedConnection and are measured in UTF-8/storage bytes.
constexpr size_t BROKER_MAX_BYTES = 149U;
constexpr size_t PORT_MAX_BYTES = 5U;
constexpr size_t USER_MAX_BYTES = 31U;
constexpr size_t PASSWORD_MAX_BYTES = 31U;
constexpr uint16_t PORT_MIN = 1U;
constexpr uint16_t PORT_MAX = 65535U;

constexpr const char *DEFAULT_BROKER = "0.0.0.0";
constexpr const char *DEFAULT_PORT = "1883";
constexpr const char *DEFAULT_ROOT_TOPIC = "mbx_root";

enum class Field {
    None,
    BrokerIp,
    BrokerUrlHost,
    Broker,
    BrokerPort,
    User,
    Password,
};

enum class Constraint {
    None,
    MaximumBytes,
    PortDecimal,
    PortRange,
};

struct ValidationError {
    ValidationError(const Field fieldValue = Field::None,
                    const Constraint constraintValue = Constraint::None)
        : field(fieldValue), constraint(constraintValue) {}

    Field field;
    Constraint constraint;
};

struct ConnectionInput {
    std::string brokerIp;
    std::string brokerUrl;
    std::string brokerPort;
    std::string user;
    std::string password;
};

struct PreparedConnection {
    std::array<char, BROKER_MAX_BYTES + 1U> broker{};
    std::array<char, USER_MAX_BYTES + 1U> user{};
    std::array<char, PASSWORD_MAX_BYTES + 1U> password{};
    uint16_t port = 0U;
    bool valid = false;
};

std::string trim(const std::string &value);

std::string extractHost(const std::string &url);

bool validateNonSecret(const ConnectionInput &input, ValidationError &error);

bool validatePassword(const std::string &password, ValidationError &error);

bool prepareConnection(const ConnectionInput &input, PreparedConnection &output, ValidationError &error);

bool copyCString(char *destination, size_t capacity, const std::string &value);

const char *fieldName(Field field);

const char *constraintMessage(const ValidationError &error);

size_t maximumBytes(Field field);

template<typename Callback>
bool withValidConnection(const PreparedConnection &connection, Callback &&callback) {
    if (!connection.valid) return false;
    return std::forward<Callback>(callback)(connection);
}

// A failed load is responsible for leaving MQTT disabled. After a valid load,
// always restore the persisted enabled preference, regardless of whether the
// one-shot connection attempt succeeds.
template<typename LoadCallback, typename AttemptCallback, typename RestoreCallback>
bool runOneShotConnectionTest(LoadCallback &&load, AttemptCallback &&attempt,
                              RestoreCallback &&restore) {
    bool configuredEnabled = false;
    if (!std::forward<LoadCallback>(load)(configuredEnabled)) return false;

    const bool connected = std::forward<AttemptCallback>(attempt)();
    std::forward<RestoreCallback>(restore)(configuredEnabled);
    return connected;
}

}  // namespace MqttConfigCore

#endif

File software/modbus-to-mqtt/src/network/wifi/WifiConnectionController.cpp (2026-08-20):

#include "network/wifi/WifiConnectionController.h"

#include <cstring>

#include "network/wifi/WifiCredentialFieldCore.h"
#include "network/wifi/WifiConfigurationStorage.h"
#include "services/TimeService.h"

namespace {

WifiConnectionState toPublicState(const ProvisioningAttemptCore::State state) {
    switch (state) {
        case ProvisioningAttemptCore::State::Idle: return WifiConnectionState::Idle;
        case ProvisioningAttemptCore::State::Connecting: return WifiConnectionState::Connecting;
        case ProvisioningAttemptCore::State::Connected: return WifiConnectionState::Connected;
        case ProvisioningAttemptCore::State::Failed: return WifiConnectionState::Failed;
        case ProvisioningAttemptCore::State::Disconnected: return WifiConnectionState::Disconnected;
    }
    return WifiConnectionState::Failed;
}

bool configureAddressing(const WifiStaticConfig &configuration) {
    if (!configuration.any()) {
        return WiFi.config(INADDR_NONE, INADDR_NONE, INADDR_NONE);
    }

    IPAddress ip;
    IPAddress gateway;
    IPAddress subnet;
    IPAddress dns1;
    IPAddress dns2;
    if (!ip.fromString(configuration.ip)
        || !gateway.fromString(configuration.gateway)
        || !subnet.fromString(configuration.subnet)
        || (configuration.dns1.length() && !dns1.fromString(configuration.dns1))
        || (configuration.dns2.length() && !dns2.fromString(configuration.dns2))) {
        return false;
    }
    return WiFi.config(ip, gateway, subnet, dns1, dns2);
}

}  // namespace

void WifiConnectionController::begin(const String &hostname) {
    const std::lock_guard<std::mutex> guard(_operationMutex);
    Serial.printf("WiFiConnectController::begin(%s) called\n", hostname.c_str());
    removeEventHandler();
    _hostname = hostname;
    WiFi.persistent(false);
    WiFiClass::mode(WIFI_STA);
    WiFi.disconnect(true, false);
    _attempt.reset();
    _eventGate.reset();
    _pendingConnection.clear();
    _activeToken = 0U;
    _eventHandlerId = WiFi.onEvent([this](const WiFiEvent_t event, const WiFiEventInfo_t info) {
        onEvent(event, info);
    });
    _eventHandlerRegistered = true;
    Serial.println("WiFiConnectController::begin() ended");
}

void WifiConnectionController::reset() {
    const std::lock_guard<std::mutex> guard(_operationMutex);
    removeEventHandler();
    WiFi.disconnect(true, true);
    _attempt.reset();
    _eventGate.reset();
    _pendingConnection.clear();
    _activeToken = 0U;
}

void WifiConnectionController::setApChannelIfNeeded(const uint8_t channel) {
    Serial.printf("WiFiConnectController::setApChannelIfNeeded(%d) called\n", channel);
    if (!channel) return;
    wifi_config_t wifiConfiguration{};
    if (esp_wifi_get_config(WIFI_IF_AP, &wifiConfiguration) == ESP_OK
        && wifiConfiguration.ap.channel != channel) {
        wifiConfiguration.ap.channel = channel;
        (void)esp_wifi_set_config(WIFI_IF_AP, &wifiConfiguration);
    }
}

bool WifiConnectionController::connect(const String &ssid, const String &password, const String &bssidText,
                                       const WifiStaticConfig &staticConfiguration, const bool save,
                                       const uint8_t channel) {
    const std::lock_guard<std::mutex> guard(_operationMutex);
    if (_attempt.isConnecting()) return false;

    WiFi.setAutoReconnect(false);
    setApChannelIfNeeded(channel);

    AttemptCore::CandidateValue candidate;
    candidate.ssid = ssid;
    candidate.password = password;
    candidate.networkConfiguration = staticConfiguration;
    candidate.save = save;
    const AttemptToken token = _attempt.start(std::move(candidate));
    _activeToken = token;
    _deadline = millis() + _timeoutMs;
    _pendingConnection.ssid = ssid;
    _pendingConnection.password = password;
    _pendingConnection.bssid = bssidText;
    _pendingConnection.staticConfiguration = staticConfiguration;
    _pendingConnection.channel = channel;

    // Arduino dispatches driver events through a separate FIFO. Stop STA while
    // leaving the setup AP running and wait for STA_STOP in that FIFO before
    // arming this attempt. Events queued by the previous connection are thereby
    // drained before the new driver connection can produce any events.
    _eventGate.awaitStationStop(token);
    wifi_mode_t mode = WiFiClass::getMode();
    if ((mode & WIFI_MODE_AP) == 0) {
        mode = static_cast<wifi_mode_t>(mode | WIFI_MODE_AP);
        if (!WiFiClass::mode(mode)) {
            fail(token, "EVENT_BARRIER_FAILED");
            return true;
        }
    }
    if ((mode & WIFI_MODE_STA) == 0) {
        mode = static_cast<wifi_mode_t>(mode | WIFI_MODE_STA);
        if (!WiFiClass::mode(mode)) {
            fail(token, "EVENT_BARRIER_FAILED");
            return true;
        }
    }
    const wifi_mode_t apOnlyMode = static_cast<wifi_mode_t>(mode & ~WIFI_MODE_STA);
    if (!WiFiClass::mode(apOnlyMode)) fail(token, "EVENT_BARRIER_FAILED");
    return true;
}

void WifiConnectionController::loop() {
    const std::lock_guard<std::mutex> guard(_operationMutex);
    if (_attempt.isConnecting()
        && static_cast<int32_t>(millis() - _deadline) >= 0) {
        const AttemptToken token = _activeToken;
        fail(token, "TIMEOUT");
        WiFi.disconnect(false, false);
    }
}

WifiStatus WifiConnectionController::getStatus() const {
    const auto snapshot = _attempt.snapshot();
    WifiStatus result;
    result.state = toPublicState(snapshot.state);
    result.ssid = snapshot.ssid;
    result.ip = snapshot.ip;
    result.reason = snapshot.reason;
    result.hasIp = snapshot.hasIp;
    result.provisioningReady = snapshot.provisioningReady;
    return result;
}

void WifiConnectionController::cancel() {
    const std::lock_guard<std::mutex> guard(_operationMutex);
    if (!_attempt.isConnecting()) return;
    const AttemptToken token = _activeToken;
    (void)_attempt.cancel(token);
    _eventGate.cancel(token);
    _pendingConnection.clear();
    WiFi.disconnect(false, false);
}
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

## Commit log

2025-05-30 added hw
    [modbus-to-x.kicad_pcb, modbus-to-x.kicad_sch]
2025-05-30 hardwiring address pins in eeproms
    [modbus-to-x.kicad_sch]
2025-06-02 new power circuit WIP
    [modbus-to-x.kicad_sch]
2025-06-02 fixed warnings
    [modbus-to-x.kicad_sch]
2025-06-19 updated hw
    [modbus-to-x.kicad_pcb, modbus-to-x.kicad_sch]
2025-06-19 updated footprints
    [modbus-to-x.kicad_sch]
2025-07-05 hardware tweaks
    [modbus-to-x.kicad_pcb, modbus-to-x.kicad_sch]
2025-07-05 added bulk ecap to max485 ic
    [modbus-to-x.kicad_pcb, modbus-to-x.kicad_sch]
2025-07-06 status leds
    [modbus-to-x.kicad_pcb, modbus-to-x.kicad_sch]
2025-07-06 board cleanup
    [modbus-to-x-B_Cu.gbl, modbus-to-x-B_Mask.gbs, modbus-to-x-B_Paste.gbp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]
2025-07-08 added receptable
    [modbus-to-x.kicad_pcb, modbus-to-x.kicad_sch]
2025-07-09 improved edge cuts
    [modbus-to-x.kicad_pcb, modbus-to-x.kicad_sch]
2025-07-10 improved trace clearance
    [modbus-to-x-B_Cu.gbl, modbus-to-x-B_Mask.gbs, modbus-to-x-B_Paste.gbp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]
2025-07-19 updated datasheets
    [modbus-to-x.kicad_sch]
2025-07-19 fixed esp32 footprint
    [modbus-to-x.kicad_pcb, modbus-to-x.kicad_sch]
2025-07-21 small trace improvements using new ESP footprint
    [modbus-to-x.kicad_pcb, modbus-to-x.kicad_sch]
2025-07-23 added missing component 3dmodels
    [modbus-to-x.kicad_pcb, modbus-to-x.kicad_sch]
2025-07-23 added custom footprints to project to avoid warnings
    [modbus-to-x.kicad_pcb, modbus-to-x.kicad_sch]
2025-08-04 added custom symbols
    [modbus-to-x.kicad_pcb, modbus-to-x.kicad_sch]
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2025-09-02 save/apply now working
    [ConfigurationRoot.h]
2025-09-05 revised hw
    [modbus-to-x.kicad_pcb, modbus-to-x.kicad_sch]
2025-09-11 refined MQTT config UI
    [ConfigurationRoot.h, modbus-to-x.kicad_pcb, modbus-to-x.kicad_sch]
2025-09-14 modbus WIP
    [modbus-to-x.kicad_pcb]
2025-09-18 new power circuit
    [modbus-to-x.kicad_pcb, modbus-to-x.kicad_sch]
2025-09-19 hw mods
    [modbus-to-x.kicad_pcb]
2025-09-20 hw updates
    [modbus-to-x.kicad_pcb]
2025-09-20 added xtal
    [modbus-to-x.kicad_pcb, modbus-to-x.kicad_sch]
2025-09-21 bom fixes
    [bom.xlsx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]
2025-10-04 WIP homeassistant discovery
    [modbus-to-x.kicad_sch]
2025-10-05 final alpha_v0.2
    [modbus-to-x-B_Cu.gbl, modbus-to-x-B_Mask.gbs, modbus-to-x-B_Paste.gbp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]
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2025-10-15 added reboot button on captive portal
2025-11-12 new ps
    [modbus-to-x-B_Cu.gbl, modbus-to-x-B_Mask.gbs, modbus-to-x-B_Paste.gbp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]
2025-11-20 lm2596 psu
    [modbus-to-x.kicad_pcb, power_tester.kicad_pcb]
2025-11-20 Revise field power voltage range in README
    Updated voltage specifications for field power in README.
2025-11-22 small updates
    [modbus-to-x.kicad_pcb]
2025-12-07 improved silkscreen texts
    [modbus-to-x.kicad_pcb]
2025-12-08 improved silkscreen texts cleanup
    [modbus-to-x.kicad_pcb]
2025-12-14 lm2596 output cap changed
    [modbus-to-x.kicad_pcb]
2025-12-15 unchecking RS485_DROP_LEADING_ZERO, as the underlying issue was fixed by proper line bias
    [Config.h]
2025-12-19 improved datapoint alloc. fixed indicator bug
    [modbus-to-x.kicad_pcb, modbus-to-x.kicad_sch]
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2025-12-23 customized partition table to allow fs upload without overwriting user configurations
    [modbus-to-x.kicad_pcb]
2025-12-23 updated schema to reflect current configuration model
    [modbus-to-x.kicad_pcb, modbus-to-x.kicad_sch]
2026-01-01 OTA and UI improvements
    [mbx_partitions.csv, modbus-to-x.kicad_pcb]
2026-01-09 added signed OTA changelog
    [modbus-to-x.kicad_sch]
2026-02-09 small trace refinements
    [modbus-to-x-B_Cu.gbl, modbus-to-x-B_Mask.gbs, modbus-to-x-B_Paste.gbp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]
2026-03-06 Fixed device bricking on failed OTA updates. - Added recovery page - Reversed FS/FW flash order
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2026-08-11 - Added password-only OTA protection setting. username removed. - Added recommendation for configuring password. Now showing protected or unprotected state and requires explicit confirmation before f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
    [Config.h]
2026-08-13 - Added strict limits for MQTT configuration fields. - Replaced unsafe configuration copies with bounded and validated storage. - Invalid MQTT updates are now rejected before ConfigFS or NVS are modi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
    [MqttConfigCore.h]
2026-08-15 - Improved MQTT and Modbus runtime. These states now have single-owner execution contexts. - Bounded queues and coherent snapshots replace cross-task access. - Configuration candidates activates atom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
    [Config.h, ModbusBus.cpp]
2026-08-20 - Provisioning now saves Wi-Fi creds only after a verified connection is made. - Fixed bug with static IPv4 or DHCP settings persistence. - Stale Wi-Fi events cannot complete, fail, or persist on a w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
    [WifiConnectionController.cpp]
2026-08-20 - Replaced fragile array-index Wi-Fi selection with BSSID-based AP identity. - Filtering now preserves the selected AP and restores its highlight. - Scans are safely refreshed rebind the same AP or f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
2026-08-22 - Bugfix: Coil commands will now only accept 0/1 and false/true. - Improvement: Register commands will now require complete, finite decimal syntax. - Bugfix: Exact bounds are checked before floating-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
2026-10-13 Refactored OTA framework: added session tracking, quiescence, progress states, and admission control.
2026-10-14 Decode and encode Modbus values by dataType; coil-write and /set fixes (#26)
    * fix(modbus): write coil ON as 1 instead of 0xFF00
    ModbusMaster::writeSingleCoil(uint16_t, uint8_t) takes the coil state as
    0/1 and builds the 0xFF00/0x0000 wire value itself. executeOwned passed
    0xFF00, which the uint8_t parameter truncated to 0, so every FC5 "on"
    command (MQTT, Home Assistant switch, HTTP execute) switched the coil off.
    Pass 1/0 and drop the redundant beginTransmission/send calls.
    Claude-Session: https://claude.ai/code/session_01Efb4JNdQJaoB2Bbt6h6dqv
    * fix(mqtt): accept write commands on <base>/set instead of the state topic
    Writable d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
2026-10-14 Support Wavin AHC 9000 (function codes 0x43/0x44)
    The Wavin AHC 9000 floor-heating controller uses Modbus RTU framing but only
    answers its own function codes and addresses registers by category, index and
    page, so every standard read returns IllegalFunction (#28).
    - WavinFrame: pure frame builder/scanner (CRC16, 0x43 read, 0x44 write,
    replies and exceptions; skips another master's traffic on the shared bus).
    - WavinClient: raw transactions over ModbusBus with RS-485 direction control;
    reads are retried once on timeout/CRC error (shared bus with a wall display).
    - Datapoints accept function 67 (0x43 read) and 68 (0x44 write) with
    category/page; address holds the register index. Reads p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
2026-10-14 README: Wavin primary element is 1-based; more confirmed registers
    The channel's primary-element field holds the element number plus one
    (0x00C1 = element 0), as niklascp's implementation also assumes. Adds the
    element assignment bitmask, status, battery scale and primary channel, and
    the packed-data comfort/eco and min/max setpoints, all read on a live
    AHC 9000.
    Claude-Session: https://claude.ai/code/session_01DpCmiansQETgYLcmy9nxx4
2026-10-14 Fixed Wavin AHC 9000 review findings: short replies, bus alignment, HTTP validation
    - Accept CRC-valid replies carrying fewer registers than requested and
    report the count actually received (polling and /api/modbus/execute).
    - Look for the reply at every buffer offset so a stale candidate claiming
    a longer frame cannot hide it; recognise another master's request by its
    own CRC so it no longer turns a timeout into InvalidCRC.
    - Reject Wavin reads with no saved datapoint and no category/page instead
    of falling back to category 0 / page 0.
    - /api/modbus/execute: reject addr/len above 65535 instead of wrapping,
    and category without page (or vice versa) instead of ignoring both.
    - Confi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
2026-10-14 Wavin: 22-register limit and register docs from Wavin's Modbus description
    Wavin's "Modbus beskrivelse for AHC 9000 styreenhed" (2013-08-14) allows
    N = 0x01..0x16 registers per 0x43/0x44 request, so kMaxRegisters is 22
    (was 32); the web UI, HTTP API docs and the stale-header test follow.
    README register table now uses the spec: thermostat status and RSSI bits,
    mode values and the week-schedule bit, min/max only limit the thermostat
    UI (0x44 writes are not clamped, verified), desired temperature, timer
    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
2026-10-14 Added pull request and issue templates
    PR template asks for a change list, the build and test commands that were
    run, what was not tested, hardware verification, and docs/schema updates.
    Issue forms for bug reports, feature requests and Modbus device support
    ask for firmware version, board revision, bus settings, configuration
    excerpts and logs with credentials removed. Blank issues stay enabled for
    questions since the repository has no Discussions.
    Claude-Session: https://claude.ai/code/session_01SWkHaQhe2NNqg9dbZUAxyA
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2026-10-14 Run native and web test suites in CI
    Adds two jobs next to the firmware build: native-tests runs the Unity
    tests with `pio test -e native-test`, and web-tests runs the Node tests
    under test/web with `node --test`. The jobs run in parallel and report
    as separate checks on pull requests. The native job uses its own
    PlatformIO cache key so it does not share the ESP32 toolchain cache.
    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
2026-10-14 Hardened CI: shared PlatformIO setup, separate caches, pinned versions
    The build and native-tests jobs now use one composite action for Python,
    PlatformIO Core and the package cache. The cache name is an input and sits
    in both the key and the restore prefix, so the build job can no longer
    warm-start from the native cache when platformio.ini changes.
    PlatformIO Core is pinned to 6.1.19, the native platform to ^1.2.1 and
    ArduinoFake to ^0.4.0, so a new upstream release cannot break the native
    tests without a repository change. The core version is part of the cache
    key. The web-tests job pins Python 3.11 like the other jobs, since one
    test starts the mock web server.
    The workflow token is lim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
2026-10-15 Correct test setup and style claims in AGENTS.md after review
    - The native test environment links ArduinoFake and ArduinoJson; the
    stubs only cover the ESP32-only headers. Stubbing Arduino.h would
    shadow ArduinoFake, so say so instead of inviting it.
    - test/sample_test.cpp includes plain units as well as *Core ones, and
    does so because the native env does not compile src/. Describe that
    practice rather than a stricter rule the suite does not follow.
    - The API route map is a plain object; only modbus_types.mjs freezes
    its tables. Name the include guard form the newest headers use and
    note that constexpr constants are mixed.
    - Add the src/include mirroring exceptions, the UI versus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
2026-10-15 Yield to the control queue between queued Modbus commands
    drainCommands() ran up to MODBUS_COMMANDS_PER_CYCLE (8) ordinary commands
    back to back without looking at the control queue again, so a priority OTA
    quiesce that arrived during the first command waited for the whole batch:
    up to 8 transactions, each one holding the bus for its full timeout when
    the device does not answer, and then the poll. The OTA quiescence bound
    assumes one.
    The ordinary loop now stops as soon as a control command is pending (a
    message in the control queue, or ordinary admission closed ahead of one),
    and loop() skips its poll while one is. The control loop runs first on
    the next loop() call and the quiesce rejects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
2026-10-15 Wavin: randomized backoff between retries, 3 attempts, 500 ms timeout
    A Home Assistant setpoint write lost both of its attempts on hardware:
    the immediate retry landed in the same burst of wall-display traffic as
    the first attempt. Retries now wait a random 100-250 ms
    (WAVIN_RETRY_BACKOFF_MIN_MS/MAX_MS), and reads and writes get 3 attempts.
    The controller answers within milliseconds and a collided request gets no
    reply at all, so the reply timeout drops from 1000 to 500 ms; a
    static_assert keeps attempts x timeout + backoff within the two seconds
    the OTA quiescence allows for one transaction (worst case 2000 ms).
    Claude-Session: https: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
2026-10-16 Wavin: baud-aware attempt timeout and a transaction budget for retries
    The retry loops copied into readRegisters and writeRegisters become one
    helper, transactWithRetry, written as a plain loop without a seeded
    status.
    An attempt now waits WAVIN_TURNAROUND_MS (WAVIN_RESPONSE_TIMEOUT_MS
    renamed, still 500 ms) for the reply to start, plus the time the largest
    expected reply takes on the wire at the bus's baud rate and character
    size, which ModbusBus now exposes. A 22-register read adds about 13 ms at
    38400 8N1 and 410 ms at 1200, where a fixed 500 ms could never receive
    it.
    Instead of a static_assert sitting exactly on 2000 ms, the attempts are
    held to WAVIN_TRANSACTION_BUDGET_MS: OTA_MODBUS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
2026-10-16 Reject bus baud rates below 1200
    The bus form has never offered a lower rate, but the schema, the page's
    validator and the firmware parser accepted any positive integer. The
    Wavin timing is checked at compile time against MODBUS_MIN_BAUD_RATE, so
    a configuration saved below it by hand or through the API could let a
    single attempt exceed the transaction budget. The parser now rejects
    such a configuration with invalid_baud_rate, the schema and the
    validator say the same, and a rejection that concerns the bus rather
    than a datapoint no longer reports a device and datapoint index.
    A baud value that is not an integer (a float, a string, a boolean or a
    number outside the int range) is rejected wi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
2026-10-17 Extract Rs485Port from ModbusBus
    ModbusBus mixed the RS-485 line with the ModbusMaster node that speaks
    standard Modbus on it. The line is now its own class, Rs485Port: UART
    configuration and serial settings, the direction pin with its guard time,
    the transaction lock (Guard), send(), discardInput(), waitForQuietLine(),
    receive capture and the error count, plus a select() hook that does
    nothing on the current one-port hardware. ModbusBus keeps the ModbusMaster
    node, bound to the port's direction control through the static callbacks,
    and the enable flag that the configuration and the OTA quiescence toggle.
    WavinClient talks to the port instead of the bus: its input drain, frame
    write and qui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
2026-10-17 Extract RtuTransport from WavinClient
    The frame scanner, the retries with their random backoff, the
    transaction budget, the baud-aware timeout and the quiet-line settle
    were written for Wavin but belong to every protocol on the bus. They now
    form RtuTransport, which runs one exchange(request, shapes) over an
    RtuLink: the request goes out, the reply is found among other masters'
    traffic by scanning at every offset, timeouts and CRC errors are retried
    while the policy's budget allows, and after a final failure the line is
    left quiet. The caller's buffer must hold the shape's largest frame; a
    smaller one is rejected before anything is sent, so a cut reply can
    never pass as a complete one.
    RtuF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
2026-10-17 - Added Micro USB port - Added header for OpenLog - Minor silkscreen updates - New buck conv. inductor improving cost
2026-10-17 Read the OTA upload address from MBX_DEV_OTA_HOST
    The two network upload environments carried hard-coded device
    addresses in upload_port, which the repository guidelines ask
    contributors not to commit. Take the address from the environment the
    same way the OTA password already is, and document both variables in
    platformio.ini, README and AGENTS.md.
    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
2026-10-17 Correct board-ID documentation after review
    An independent review of the first commit found the documentation
    ahead of the repository: firmware support for reading the ID was
    described as existing and a compatibility table was referenced that
    does not exist yet. Both are now described as planned.
    hardware/BOARD-ID.md also gains the parts and footprints, the board
    location of the resistors, the ESP32 errata note for IO36/IO39, the
    ADC1 and Hall-sensor remark, a warning that an unfitted pair floats,
    the --exclude-dnp flag for position files, the sources behind the 2 k
    presence resistor, and a checklist for bumping the revision (text
    variable in either editor, DNP marks, the schematic note, th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
2026-10-18 Wavin multi-write: reject empty `values`, cover peer-write recognition, fix docs
    - POST /api/modbus/execute: a present but empty `values` is rejected with
    HTTP 400 like any other unparsable list, instead of falling through to a
    write without a value (HTTP 200, code 3). The parameter helper treats an
    empty value as absent, so presence is checked directly.
    - The clock-page test says why a category 5 frame from the display is
    dropped byte by byte (an odd byte at offset 2 never matches the reply
    shape) and adds a category 6 schedule write: with write frames of up to
    kMaxRegisters the scanner recognises the display's 7-word request as peer
    traffic and the reply behind it is found wi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
2026-10-21 Pin espressif32 to 7.1.3 and build releases like CI
    The Release OTA run for 8.2.0-beta failed in the build step. The platform
    line was unpinned and the release workflow installs the newest PlatformIO
    Core with no package cache, so it resolved espressif32 8.0.0 (Arduino core
    3.3.12, GCC 14). On that toolchain ModbusTopicBuilder.cpp no longer
    compiles: std::toupper and std::tolower came in through WString.h on the
    old core. CI kept passing because its composite action restores a package
    cache that still held 7.1.3.
    - platformio.ini: every ESP32 environment pins espressif32@7.1.3, the
    version the last release and CI build with. The pin also changes the CI
    cache key, so CI installs exactly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
2026-10-21 Add the hardware compatibility table
    One row per marked hardware revision with its tag, board-ID code,
    lifecycle status, minimum and tested firmware, starting with the
    planned 1.0.0 board at code 1. The historical spins table that resolves
    the prototype names (alpha tags, gerber folders, inventory label, title
    block) moves here from the release policy and names a commit that still
    contains the removed gerber folders.
2026-10-21 Adopt the hardware release policy
    Commit the hardware revision and release management policy as
    hardware/RELEASING.md with status accepted. The content is the reviewed
    proposal; the state description is marked as the situation at adoption,
    the historical spins table now lives in COMPATIBILITY.md, the adoption
    sequence becomes a short pointer, and the board-ID section no longer
    mentions refusing a board, which contradicted its own rule that nothing
    is built on the value.
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2026-10-21 Stop naming the removed export folder outside the historical table
    The situation snapshot and the storage rule in the release policy and
    the hardware paragraph in AGENTS.md still spelled out the deleted
    gerber folder path. The compatibility table resolves the old names and
    .gitignore carries the path, so nothing else needs to point at it.
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2026-10-21 Correct the historical spins record and the release-asset wording
    The rev2 folder on main held a re-export from 2025-11-06 that was
    committed with the new power supply, not the v0.2-alpha export, which
    exists at the tag and in the release archive. The table now has a row
    per export, names the commit that introduced the files and says when
    that commit is not the design state the gerbers came from. The v0.1-alpha
    GitHub release carries a BOM, gerbers and PDFs, not notes only.
    AGENTS.md and README.md now scope the hw-v<rev> releases and the
    untracked-outputs rule to 1.0.0 onwards and name the historical
    v0.2-alpha folder as the tracked exception.
2026-10-21 Align the policy with the board and the compatibility table
    The header lines rendered as one paragraph and repeated the date. The
    marking example now matches the silkscreen text MBX HW <rev>. The board
    identification section described the pins as unconnected and repeated
    the pin map; it now records the rationale and points at BOARD-ID.md.
    The compatibility table uses the lifecycle's own stage name, draft, and
    its minimum-firmware column is no longer tied to the hardware-tag
    filter, which the policy itself calls repository hygiene rather than a
    gate.
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2026-10-21 Keep the maintainer's inventory out of the public documentation
    The stock-location symbol field and the inventory part numbers are the
    maintainer's private inventory. They stay in the KiCad project but are no
    longer required by the policy, checked by the release process or exported
    into the release BOM, and the historical table no longer names the
    inventory assembly label.
